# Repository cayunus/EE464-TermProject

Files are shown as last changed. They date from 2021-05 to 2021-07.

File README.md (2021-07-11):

# EE464-TermProject
This repository includes the work put into the design of an isolated DC/DC converter with a 12V output and 100W rating.

Final Presentation: https://docs.google.com/presentation/d/1tAQgM4lNq-ox6lCjjR08sszLsAYqykTbK8jtL-5Cm6U/edit#slide=id.p

Final Report: https://docs.google.com/document/d/1Ga_3vTAyOD3y9dfrS9bvXqfX1RUAF8NENX0YpGBZcNM/edit?usp=sharing

Component List: https://docs.google.com/spreadsheets/d/1R3LbDUZQGh2-h5aSoq4ABOOYQwFWA9nZVz4NNkLxFJc/edit?usp=sharing

Complete Simulation Report: https://docs.google.com/document/d/1Nri5DbtKmKyNQxO-GPV3UCYGi9CR-nUp9evS7hW1Gps/edit?usp=sharing

How to Add .lib files in LTspice: https://www.analog.com/en/technical-articles/ltspice-simple-steps-to-import-third-party-models.html

How to obtain Bode Plot in LTSpice: https://www.analog.com/en/technical-articles/ltspice-basic-steps-in-generating-a-bode-plot-of-smps.html

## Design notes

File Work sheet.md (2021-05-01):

# Work Sheet Rules
* This file is created to use as a work sheet.
* Work sheet can be used for any thing:
  * Important points
  * Question in the mind
  * Problems
  * Lessons learned from experiences
  * Good sources, books and websites.
  * Plans
  * ....

## Important Points
- The chosen topology: > Flyback converter
- Optimization for loss, size and price is highly needed for design process. GUI has been constructed to understand relations between parameters. GUI will be used as tool to define some constraints, requirements and relation for optimization. 
## Plans

- <details>
  <summary>15.04.2021</summary>
  <markdown>
   - Flyback converter controllers have been researching
    - LT8316 has been selected as controller.
    - Controllers have low input voltage limits can be biased with some LDO application with BJT or Mosfet, which results in increase in alternatives of controller.
    - PowiGan controller from Power Integration is kept as option due to advantages of PowiGan in terms efficiency(No opto, Synchronous drive, GaNFET) and compactness. If the controlle for PowiGan can be succeeded, it can be used. 
  </markdown>
</details>

## Questions
- What are parameters that affect selection different shapes of cores?
## Don't reinvent the tire (Lessons)

## Questions&Answers
## Useful Resources and Links
- Information and calculation about saturation of a core visit the [page](http://pigeonsnest.co.uk/stuff/core-saturation.html)
- Core and Shape selection from magnetics [page](https://www.mag-inc.com/Design/Design-Guides/Inductor-Cores-Material-and-Shape-Choices)
## Working sheet
### Halid
### Mehmet
### Yunus

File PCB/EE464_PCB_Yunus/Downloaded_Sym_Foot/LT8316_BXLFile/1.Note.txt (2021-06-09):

NOTE: 

1. BXL files provided represent each model for this generic that share the same package. 

2. Please visit Ultra Librarian Online Reader to convert BXL file into CAD file of your liking.
https://www.ultralibrarian.com/products/online-reader

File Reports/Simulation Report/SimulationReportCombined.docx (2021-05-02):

ELECTRICAL AND ELECTRONICS ENGINEERING DEPARTMENT

EE464 POWER ELECTRONICS – II

COMPLETE SIMULATION REPORT

Halid Filiz 2304632

Mehmet Kılıç 2232262

Yunus Çay 2166148

# 1. Introduction

In this project, we are expected to design an isolated DC-DC converter that is similar to one that is used in Tesla Model S. For this purpose, requirements are analyzed first. The designed circuit should satisfy the requirements below.

- Minimum Input Voltage: 220V
- Maximum Input Voltage: 400V
- Output Voltage: 12V
- Output Power: 100W
- Output Ripple: 4%
- Line Regulation: 3%
- Load Regulation: 3%

After assessing the requirements carefully, the design process is started. First, a suitable topology is selected by discussing the advantages or disadvantages of each topology. After determining the topology, a controller IC options are discussed and the most suitable one is selected. Circuit design process is started with controller IC and other circuit parameters are selected by considering the limitations and requirements of the controller, which are stated şn the datasheet.

After determining the circuit parameters, ideal and non ideal simulations are conducted. According to the simulation results, some changes are made and commercial products are selected for some important power components like switches, capacitors and inductances. Also, magnetic design for the transformer is started.

In this report, work done until now is represented. After taking feedback, design is going to be optimized and improved.

# 2. Topology Selection

To design this isolated DC/DC converter, we had to start by choosing a topology that satisfied our needs. The first was that this converter had to have the input and output isolated from each other. This means that we are limited to isolated topologies. The topologies that we have considered for the design are the flyback, forward and push-pull converter topologies. There are certain advantages and disadvantages for using each of these converters.

One advantage of the flyback converter is that it uses the transformer core as an energy storage element, making an extra inductor unnecessary. This situation makes flyback is a cheaper and simpler option.

Moreover, the group members have experience with flyback converter design from their summer practices and part-time working activities, which makes the flyback converter design process much easier. Therefore, flyback converter is selected to be the primary design option for this project.

While the topologies themselves are important, we must also consider the available IC controllers on the market while making our decision since if we do not have an proper IC for our topology the design is pretty much impossible. There are certain large IC controller manufacturers that have simulation models for their ICs like Analog Devices and Texas Instruments which would make our design process much easier. Therefore, controller ic election holds a crucial role in converter design.

# 3. Controller IC Selection

After researching the conventional controllers, some ics are determined to be possible options are their advantages and disadvantages are discussed. The first option was InnoSwitch3-EP.

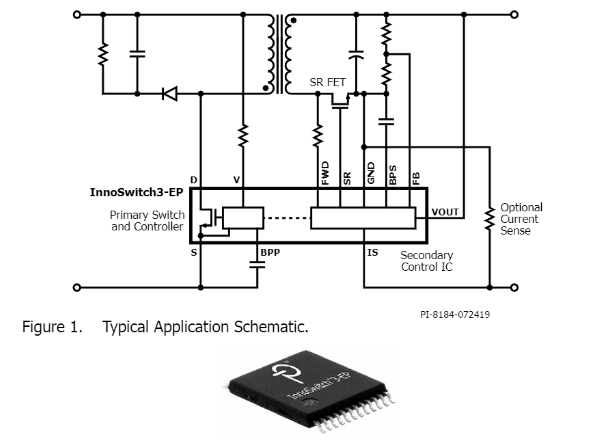
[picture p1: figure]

Figure 1 Alternative controller IC - InnoSwitch3-EP

This controller has an internal GaN MOSFET, which increases the switching efficiency. Also it provides synchronous drive in a single chip. According to the datasheet, no heatsink is required up to 100W. However, there is no simulation model provided for this controller and some details might be missed if it was manually modelled. Therefore, this controller is kept as a back-up plan.

Other two options are LT8316 and LTC3805 manufactured by Analog Devices. Since these devices have built-in models in LTSpice, it is logical to use ICs manufactured by AD. Both of these ICs are used for conventional Flyback Converters with the difference between them being the control and feedback mechanisms. The LTC3805 is a current mode controller with an adjustable frequency between 70kHz and 700kHz. For isolated feedback, this controller must be used in tandem with an opto-coupler driver and an opto-coupler. The advantage of this is that the load and line regulations are essentially perfect, and the frequency of the controller is constant.

The LT8316 on the other hand is a Quasi-resonant boundary operation mode controller and takes its feedback from the third wind of the transformer. The operation frequency of this controller changes depending on the load and while it has very good load and line regulation compared to other no-opto controllers, it does not give the same performance as a controller with an opto-coupler. The main advantage of the LT8316 is that it uses less parts since there is no need for an opto and also that it can be naturally started and then fed from the input and third windings. Both ICs are simulated, and it is seen that both of them satisfy the given conditions and are both suitable designs but in the end we must decide on one of them to continue with our project. Since LT8316 requires less parts, a simpler and cheaper design is possible if it is used. Therefore, LT8316 is selected as the controller of the designed circuit. Datasheets of each IC are provided in the Github repository.

# 4. Transformer Design

Flyback converter isolates a primary side and a secondary side with a transformer. Transformer can be used to step up or down an input voltage according to turns ratio. Besides, input-output relation is the same as buck boost converter. Input-output relation is shown in Equation (1).

| V_o =(N_s)/(N_p)D/(1-D)V_(in) | (1)

Transformer is mainly used for the applications transmitting energy without storage. However, transformer of flyback converter stores an energy, and then passes it to secondary side, which is the reason for why flyback transformer is also called as coupled inductor. Hence, considerations for energy stored, saturation current, inductance are important for transformer design. The design of transformer is started with application information given in the datasheet.

Table 1 shows some system level information and controller requirements having an impact on the transformer design.

Table 1 Parameters for the transformer design

Description | Symbol | Value
Input voltage range | Vin,min - Vin,max | 220V – 400V
Output voltage | Vo | 12V
Max. output power | Pout | 100W
Max. switching frequency | fs | 140kHz
Min. Switch off time* | tOFF(MIN) | 800ns
Min. Switch on time* | tON(MIN) | 300ns
Backup time* | tBU | 50μs

* These parameters will be explained in detail while calculating their limitations on primary inductance.

Application information given in the datasheet determines the minimum and maximum limits for the primary, magnetizing, inductance due to parameters given in Table 1 such as tOFF(MIN), tON(MIN) and tBU. Before finding the limitations, the peak of the primary current should be determined according to working principle of controller and the delivered maximum output power. While the minimum current limit of the controller affects the limitations of primary inductance due to tOFF(MIN) and tON(MIN), the maximum output power has to be satisfied according to magnetic energy storage shown in Equation (2).

| E_(mag) = 1/2Li^2 | (2)

The maximum peak current in primary side can be found from the desired output power. Since the peak current is observed at maximum power and the controller has boundary mode control, the peak current can be calculated as seen in Equation (3). Efficiency is taken as %80 as a safety margin due to practical considerations.

| I_(SW(MAX)) =(2P_(out))/(ɳV_(in) D)=3.75A V_(in) =220V, ɳ=0.8(Eff),P_(out) =100W | (3)

## 4.1. Limitations of Primary Inductance

### I. tOFF(MIN) – Minimum Switch Off Time

The feedback of the output voltage is given through the tertiary winding. The nonzero voltage between the tertiary winding is created when the secondary current flows. The required minimum time to sample voltage by the sample-and-hold error amplifier is 800ns. “In order to ensure proper sampling, the secondary winding needs to conduct current for at least 800ns.” [1] The limitation due to tOFF(MIN) is given in Equation (4).

| L_m ≥(t_(OFF(MIN)) N_p (V_o +V_F ))/(I_(SW(MIN)))=0.11mH N_p =8 Turns, V_F =0.7V(Diode), I_(SW(MIN)) =0.2*I_(SW(MAX)) =0.75A | (4)

### II. tON(MIN) – Minimum Switch Off Time

The controller has a minimum switch on time for the sake of blanking initial switch turn-on current spike. The current, ISW(MIN), should not be reached for tON(MIN), which creates restriction on the selection of flyback transformer in terms of magnetizing inductance. The limitation due to switch on time is determined in Equation (5).

| L_m ≥(t_(ON(MIN)) V_(in(MAX)))/(I_(SW(MIN)))=0.16mH | (5)

### III. Power Storage Capability of the Transformer

Equation (2) shows the magnetic energy stored in an inductor for a given current and inductance. Since the flyback transformer stores magnetic energy due to working principle of flyback converter, the inductance of transformer should be able to store sufficient power. Equation (6) shows the limitation of the inductance due to magnetic energy storage.

| L_m ≥(2(V_o +V_F )I_(o(MAX)))/(ɳI_(SW(MAX))^2 f_(s(MAX)))=0.14mH | (6)

### IV. Backup Time

Backup timer is stimulated to avoid low output voltage levels. Backup timer turns the primary switch on unless the secondary side diode turns off. This feature restricts the inductance value with maximum limit. Limitation of inductance of flyback transformer due to backup time can be seen in Equation (7).

| L_m <(0.8 N_p (V_o +V_F )t_(BU))/(I_(SW(MAX)))=1.08mH | (7)

## 4.2. Determination of Turns Ratio

The output voltage is lower than the input voltage level. Transformer should step down the input voltage for reasonable values so that sensitivity of duty cycle should not be high, i.e., duty cycle below %10 is problem for controllers. Therefore, the turns ratio should be high as much as possible to keep duty cycle in a range between %50 and %20.

Turns ratio has also impact on breakdown voltage of semiconductors. Table 2 shows maximum terminal voltages of the primary switch and the secondary diode. The turns ratio has reverse effect on the semiconductors. While turns ratio, N, increases reverse voltage of the primary switch, it reduces reverse voltage of the secondary diode.

Table 2 Relation between turns ratio and reverse voltage of the semiconductors

Semiconductor | General Formulation for Reverse Voltage
Primary switch | VDS = Vin + N(Vo + VF) + VLeakage
Secondary diode | VR = (Vin/N) + (Vo + VF)

The turns ratio is selected as 8, which keep the duty cycle between %20 and %30. Also, this selection can be optimized value in terms of reverse voltage of semiconductors and duty cycle. The increase in reverse voltages results in increase in switching losses and decrease in safety margin of devices. Duty cycle of the flyback converter in a range of input voltage is shown in Figure 2.

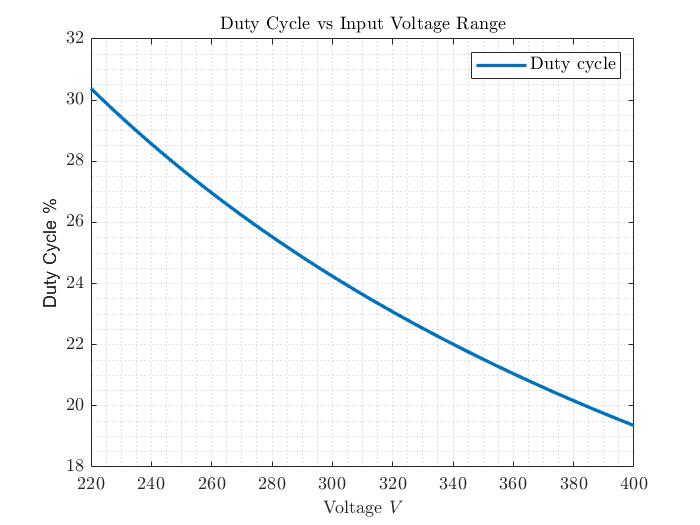
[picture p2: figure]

Figure 2 Duty cycle vs input voltage range for 8 turns ratio, N

## 4.3. Determination of the Primary Inductance

In the part 0 , 0.16mH and 1.08mH are founded as minimum and maximum limitations, respectively. The value between the limits may probably work. However, safety margin for each limit should be determined to eliminate unexpected practical issues. The safety region for each limit can be taken as %25 of limiting value above and below for minimum and maximum limits, respectively. Hence, the primary inductance value should be between 0.2mH and 0.81mH.

The boundary mode control requires variable switching frequency according to the load. When the primary switch is on, the inductor current starts from the zero. Therefore, the frequency relation between frequency and inductance for the same input voltage and output voltage is obvious, which is shown in Equation (8). Since duty cycle and turns ratio is constant, switching frequency and primary inductance are inversely proportional for the same amount of inductor current ripple. The inductor current ripple is determined according to output power.

| ΔI_(L,ON) =(DT_s V_(in))/(L_m) ΔI_(L,OFF) =((1-D)T_s (V_(in) +N(V_o +V_F )))/(L_m) | (8)

Transition to DCM occurs as the load decreases. Duty cycle calculation in DCM can be seen in Equation (9). Both calculations are the same except the Pout, Vo, and R relation.

| D=(V_o)/(V_(in))(√(2L_m f_s))/(√R) D=(√(2P_(out) L_m f_s))/(V_(in)) | (9)

Supply of the input power occurs during the on time of primary switch. Therefore, the current ripple of the inductor is directly related with the delivered power. Equation (10) shows the inductor current ripple calculation in DCM, which shows that Lm and fs are also inversely proportional in DCM.

| ΔI_L =(V_o √2)/(√(RL_m f_s)) | (10)

According to analysis of the relation between Lm and fs, increase in Lm results in low switching frequency, hence, low switching loss. On the other hand, boundary mode and DCM eliminate turn-on loss of the primary switch and reverse recovery of the secondary diode. Even if the increase in Lm can be beneficial for switching losses, the tradeoff due to increase in Lm is increase in size of flyback transformer and increase in windings, which causes more copper and core losses. The question that there is a relation between copper, core losses and frequency. Actually, this type of relations are the signs of need in optimization.

After considering iterative relation between Lm and fs, the Lm, primary inductance, is chosen as 0.4mH.

## 4.4. Core Selection

Core selection is based on shape of a core, size of a core and magnetic characteristics of a core. First, selection based on magnetic characteristics of a core is analyzed.

### I. Magnetic Characteristics of Core

General approach for the selection of core type is divided into two for flyback transformer; distributed air-gap powder cores and gapped ferrite cores. Both type of cores has advantages. For example, ferrite cores provide a core with more permeability. On the other, distributed air-gap powder cores may have less core loss compared to gapped ferrite cores.

Distributed air-gap powder core is selected based on magnetic characteristics, which can stimulate an efficiency, winding area and mechanical robustness.

Powder cores are classified. These classifications are mainly based on core loss, maximum flux density, permeability, and cost, which can be seen in Figure 3 taken from the Magnetics. Kool Mu is selected due to optimal permeability and core loss values. Besides, Kool Mu is preferred due to relative low prices.

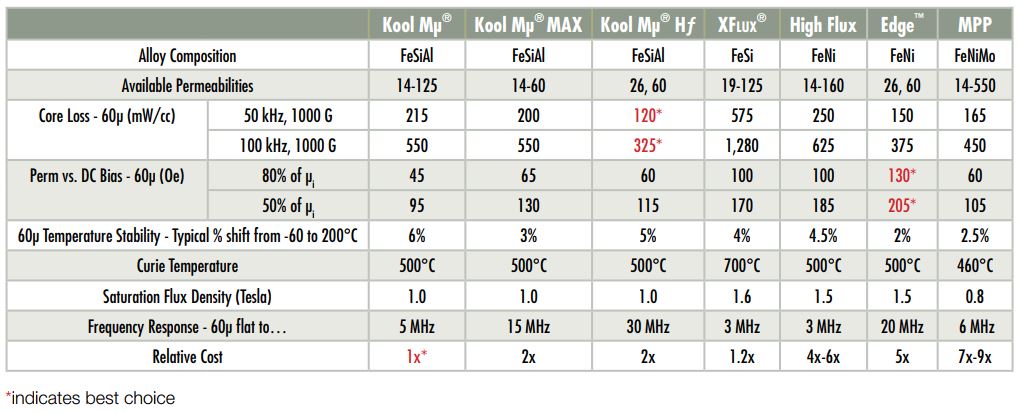
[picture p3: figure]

Figure 3 Classification of powder cores [2]

### II. Shape of Core

Common preference for flyback transformers is toroidal shape. The copper loss can be decreased with both toroidal shape and E shape according to the current situation. While toroidal shapes have permeability between 14μ-125μ, E shapes have maximum 90μ relative permeability. However, E shapes have relatively higher Ae, area. Also, the window area may be higher in toroids. Hence, toroidal shape is selected.

### III. Size of Core

Size of core will be determined from available manufactured cores. Cores are researched on Magnetics (https://www.mag-inc.com/). Selected cores are tested whether they satisfy limitations due to inductance, flux density, saturation current, fill factor. The constructed GUI on MATLAB is used to test scores. Constructed GUI can be seen in Figure 4.

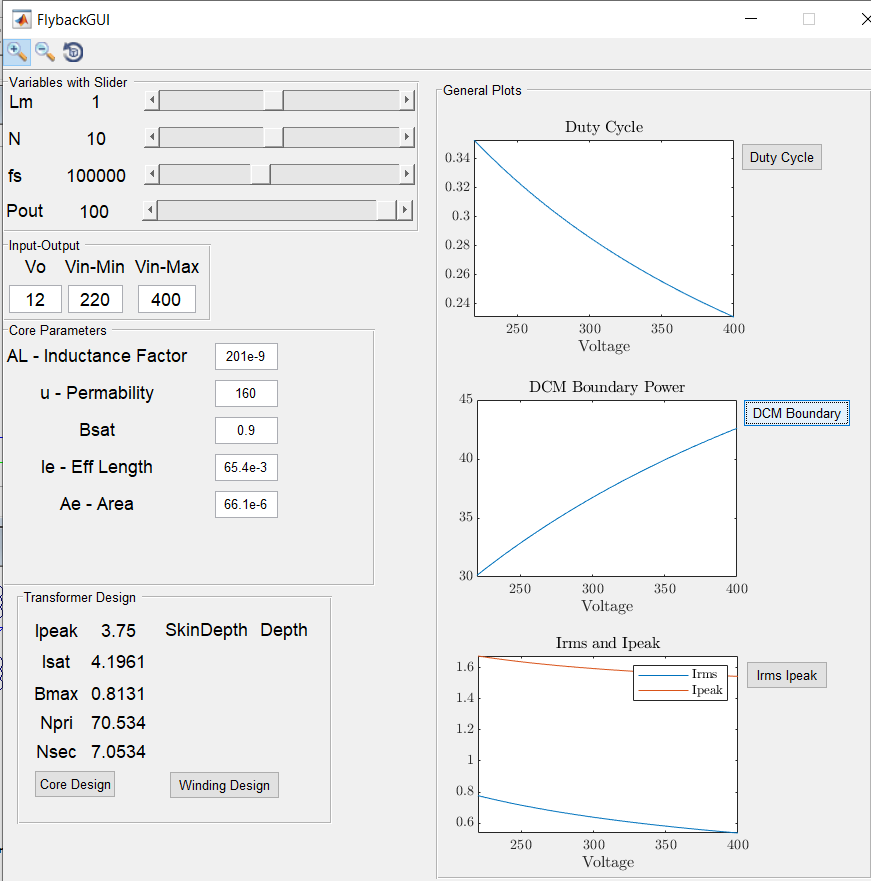
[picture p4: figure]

Figure 4 The constructed GUI on MATLAB for flyback converter design

Peak current value of the primary side is calculated ISW(MAX) that equals to 3.75A with safety margin. Safety margin is determined according to %80 efficiency of converter. The safety margin for saturation current of a core can be taken as %10, since the efficiency creates a sufficient safe region. Hence, minimum saturation current is 4.1A.

Kool Mu cores have 10,500 Gauss saturation level, which is approximately equal to 1 Tesla. Since the saturation current and created maximum flux density are proportional to each other, saturation can be checked from both created maximum flux density and peak current of the primary side.

Copper losses are also important due to AC resistance and number of windings. The optimization for copper losses based on core selection can be stimulated with selection of cores with high inductance factor, AL.

Equation (11) shows the calculation of saturation current and the created maximum flux.

| I_(sat) =(B_(sat) A_e)/(√(L_m A_L)) B_(max) =(N_p I_(peak) μ)/(l_e) | (11)

Table 3 shows the comparison of different cores. Table 3 shows the cores are in order from high volume to low volume. Core 3 is the most suitable one for required saturation limits. Hence, the core 3 is selected. Inductance factor would be more to decrease windings but there is no available Kool Mu core.

Table 3 Comparison Kool Mu cores in different sizes and inductance factors

Parameters | Core 1 930 | Core 2 350 | Core 3 310
Bsat (Tesla) | 0.9 | 0.9 | 0.9
μ - Permeability | 125 | 125 | 125
AL – Inductance factor(nH/T^2) | 157 | 105 | 90
Le – eff length (mm) | 63.5 | 58.8 | 56.7
Ae – Area (mm2) | 65.4 | 38.8 | 31.7
Isat (A) | 7.42 | 5.4 | 4.76
Bmax (Tesla) | 0.47 | 0.62 | 0.69
Np (Turns) | 50.5 | 61.7 | 66.7
Ns and Nthird (Turns) | 6.3 | 7.7 | 8.3

## 4.5. Winding and Fill Factor

Maximum switching frequency of the controller LT8316 is 140kHz. However, 140kHz switching is not observed at high load. LT8316 works in boundary mode for high load and as load increases, switching period should be increased according to Equation (8). Thus, AC resistance is not as much as higher at high load. Skin depth is relatively low at high voltage. Figure 5 given in datasheet also explains the case.

Figure 5 Switching frequency vs load, LT8316

Cable diameter should not be selected according to maximum switching frequency. The selection of cable according to maximum switching frequency may cause selection of cable having small area so that conduction losses at high load becomes high.

Even if the most reliable option to calculate AC resistances due to skin effect and proximity effect is finite element analysis, there are also other methods such as Dowell’s equation. These calculations will be done after simulation. Now, the skin depth is only calculated, and it can be seen in Equation (12). Output current equals 8.3A at full load, which results in approximately 60 kHz for 320V input. Hence, we can calculate the skin effect at 60kHz switching frequency. Besides, temperature of copper is assumed 80°C.

| δ=1/(√(πf_s σ_(Cu) μ_(Cu)))=0.296mm | (12)

When radius of a cable is selected as equal to skin depth, the whole area of the core can be used so that there will be no excessive cable thickness. As the frequency increases, AC resistance will increase. However, since the load will become less, copper loss can be negligible. AWG23 cable can be used for the primary side.

The current passing through the secondary side cable is eight times of the primary side current and the frequency is the same. At full load, secondary side should be capable to sink 8.3Adc, 11Arms. Since the ampacity of AWG23 for 75°C rating at 30°C ambient is approximately 5A, two parallel winding of AWG23 cable can be used. On the other hand, the tertiary winding can be wound with AWG30. Since the tertiary winding is solely used to get feedback, there is a very small current. Table 4 shows the windings details and fill factor.

Table 4 Transformer cable sizes and fill factor

| AWG | # of Turns | Copper Area
Primary | 23 | 67 | 17.3 mm²
Secondary | 23 | 8.3 x2 | 4.3 mm²
Tertiary | 30 | 8.3 | 0.83 mm²
Total | NA | 92 | 22.43 mm²
Fill Factor | (22.43mm^2)/(139mm^2)=0.16

# 5. Simulations

After finalizing the analytical calculations, the simulation model is constructed and simulated. For simulations we are using LTSpice since we have opted to use controllers manufactured by Analog Devices. LTSpice is a SPICE-based analog electronic circuit simulation software that is produced by the semiconductor manufacturer Analog Devices. It is the most widely used distribution of the SPICE software. Here the LTC3805 and LT8316 designs have been analyzed and the resulting waveforms have been taken. The efficiency report has been added for the LTC3805 design but could not be done for the LT8316. Though from the simulations we observed similar efficiency values for both.

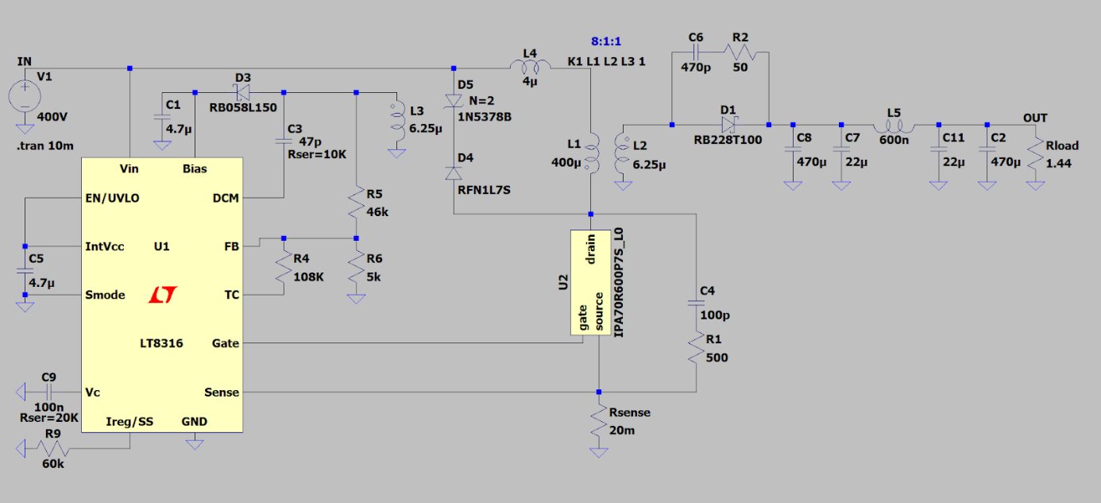
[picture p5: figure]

Figure 6 LTSpice schematic for the No Opto Flyback Converter (LT8316)

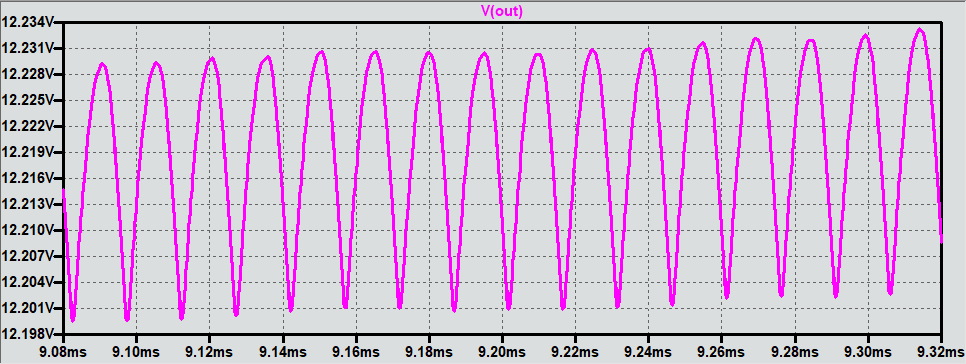
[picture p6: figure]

Figure 7 Output voltage of converter at full load and 400V input (LT8316)

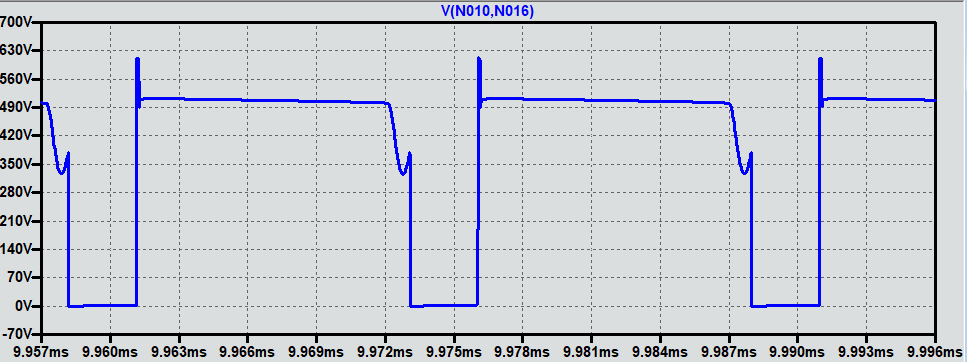
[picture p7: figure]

Figure 8 Voltage on the MOSFET at full load and 400V input (LT8316)

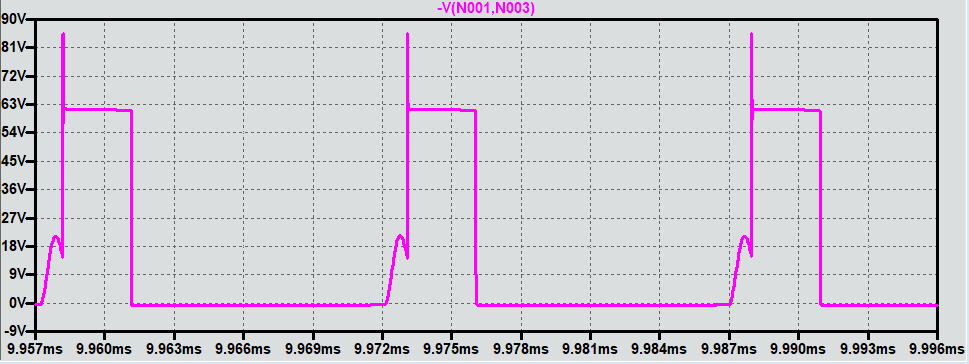
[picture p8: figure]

Figure 9 oltage on the Diode at full load and 400V input (LT8316)

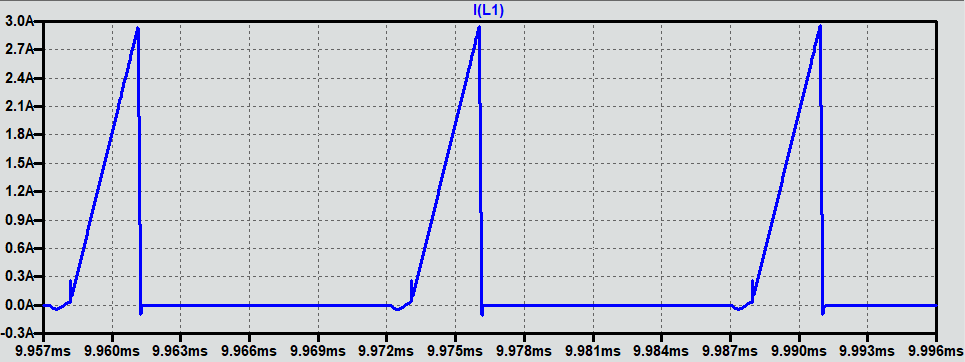
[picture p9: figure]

Figure 10 Current waveforms of the transformer’s primary at full load and 400V input (LT8316)

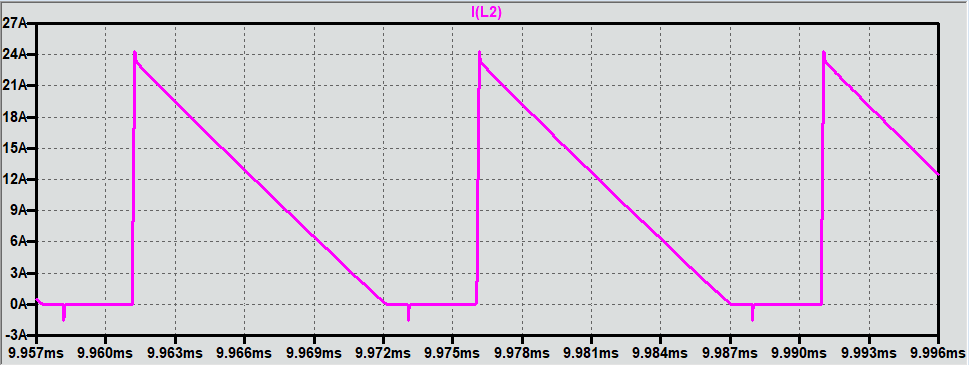
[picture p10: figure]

Figure 11 Current waveforms of the transformer’s secondary at full load and 400V input (LT8316)

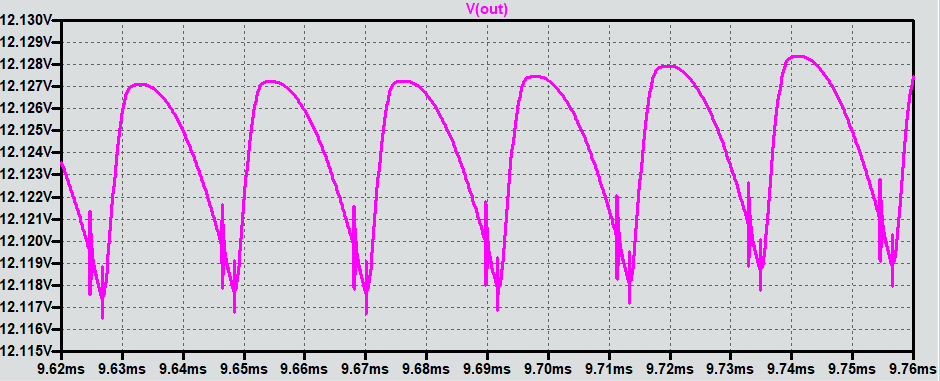
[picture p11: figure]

Figure 12 Output voltage of converter at 10% load and 220V input (LT8316)

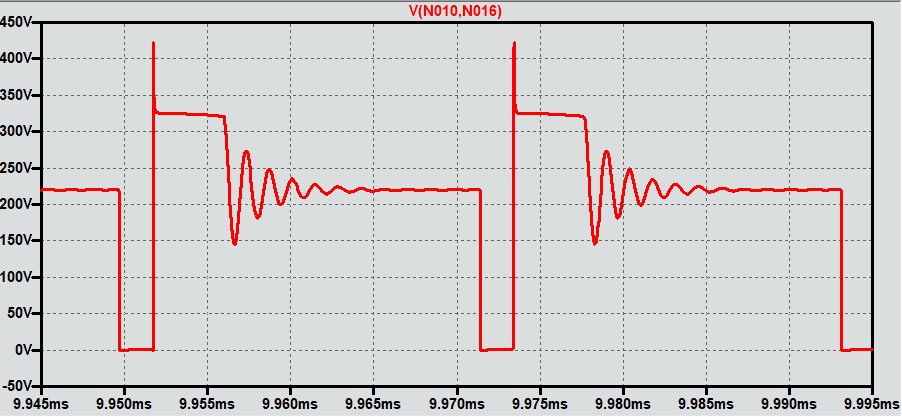
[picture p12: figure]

Figure 13 Voltage on the MOSFET at 10% load and 220V input (LT8316)

Figure 14 Voltage on the Diode at 10% load and 220V input (LT8316)

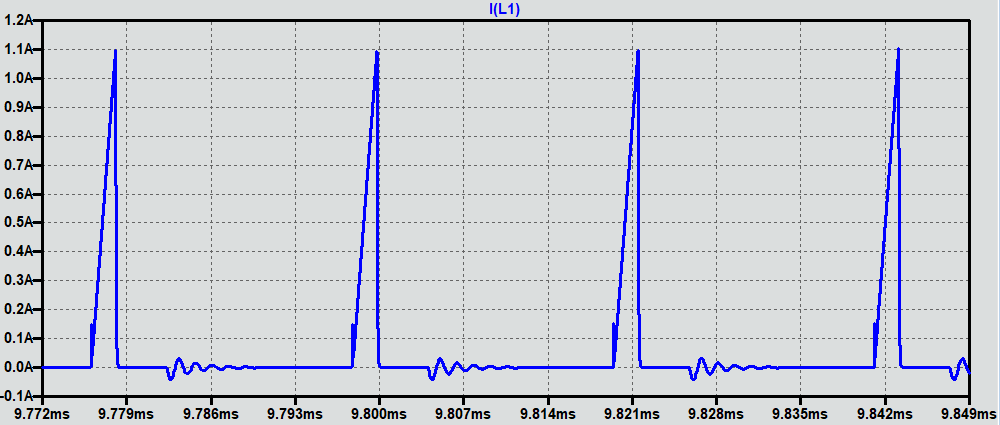
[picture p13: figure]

Figure 15 Current waveforms of the transformer’s primary at 10% load and 220V input (LT8316)

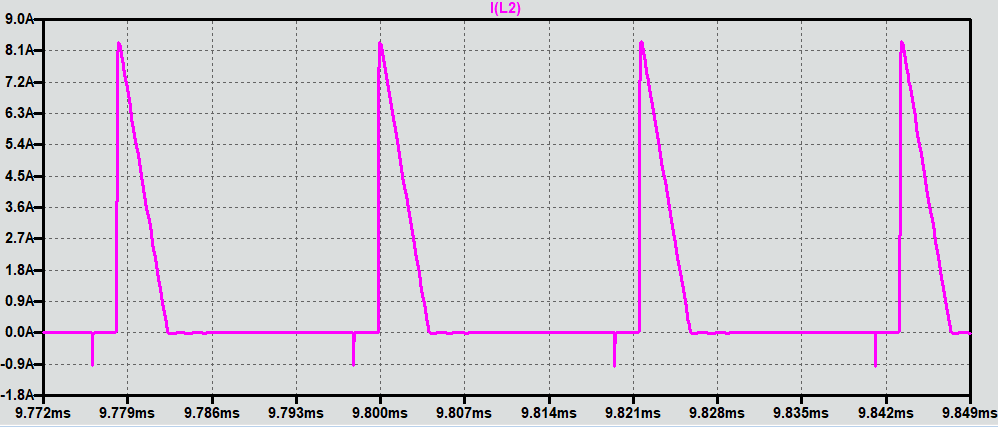
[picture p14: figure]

Figure 16 Current waveforms of the transformer’s secondary at 10% load and 220V input (LT8316)

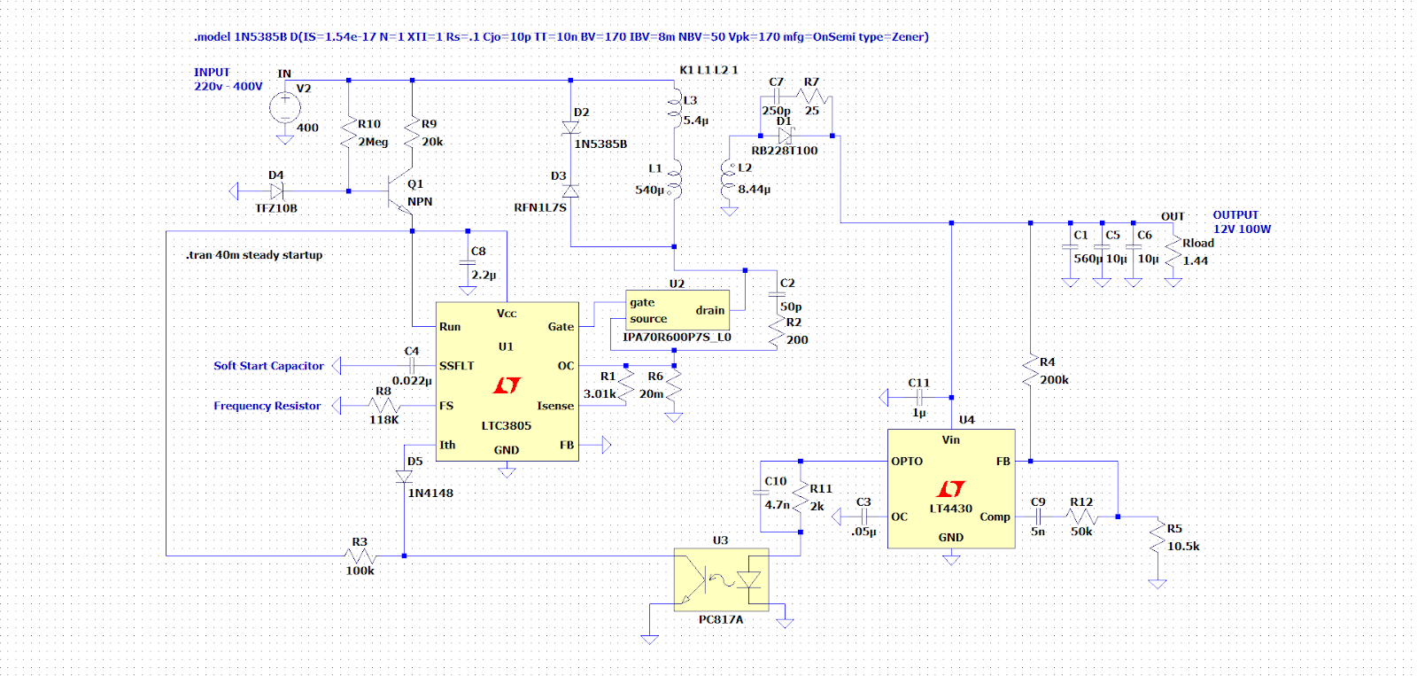
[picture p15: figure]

Figure 17 LTSpice schematic for the Flyback Converter with Opto (LTC3805)

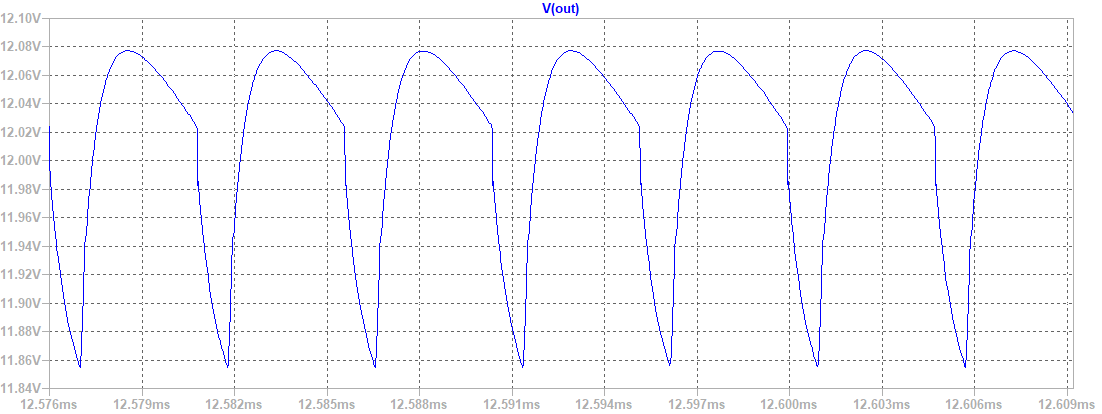
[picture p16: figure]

Figure 18 Output voltage of converter at full load and 400V input (LTC3805)

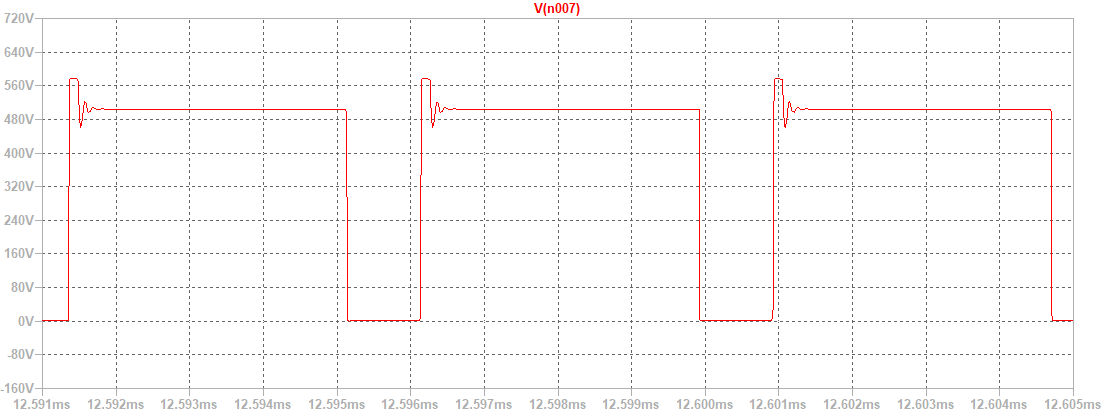
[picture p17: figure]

Figure 19 Voltage on the MOSFET at full load and 400V input (LTC3805)

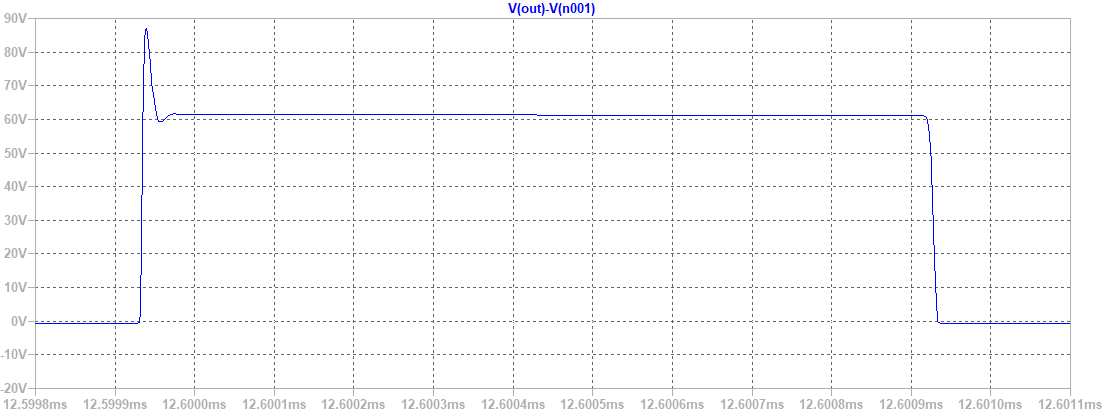
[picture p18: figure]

Figure 20 Voltage on the Diode at full load and 400V input (LTC3805)

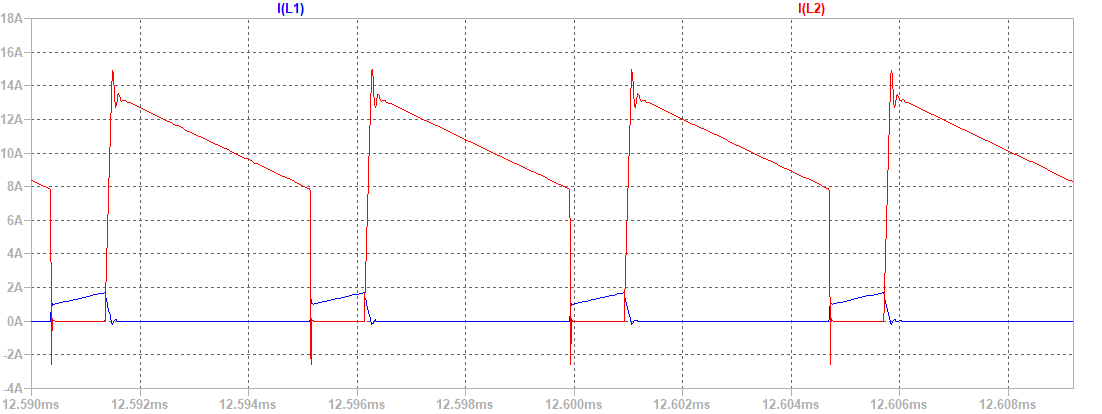
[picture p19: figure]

Figure 21 Current waveforms of the transformer’s primary and secondary at full load and 400V input (LTC3805)

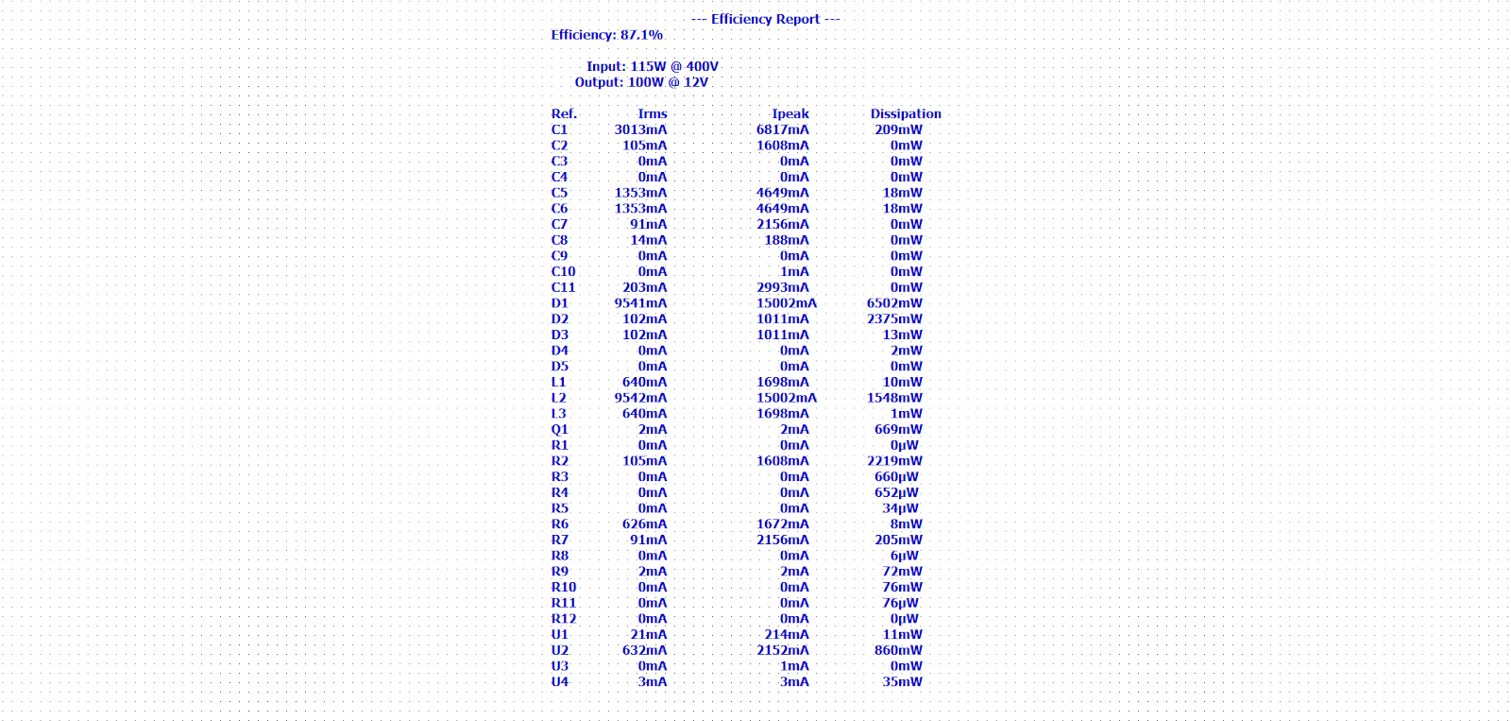
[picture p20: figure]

Figure 22 Efficiency report from LTSpice for the full load 400V input case (LTC3805)

Figure 23 Output voltage of converter at 10% load and 220V input (LTC3805)

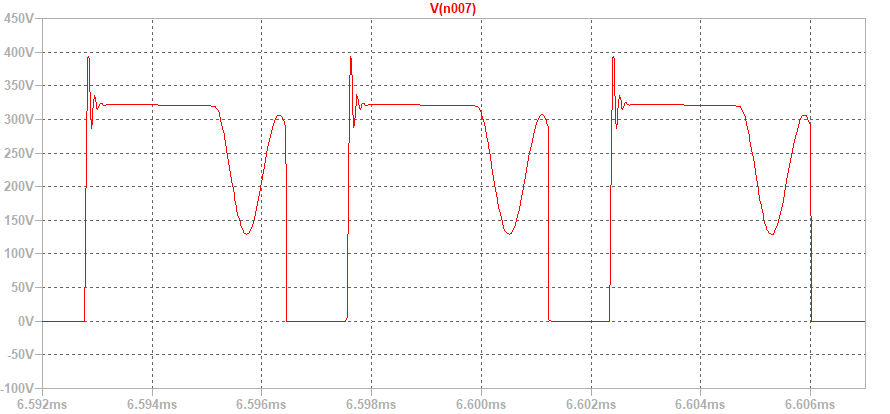
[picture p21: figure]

Figure 24 Voltage on the MOSFET at 10% load and 220V input (LTC3805)

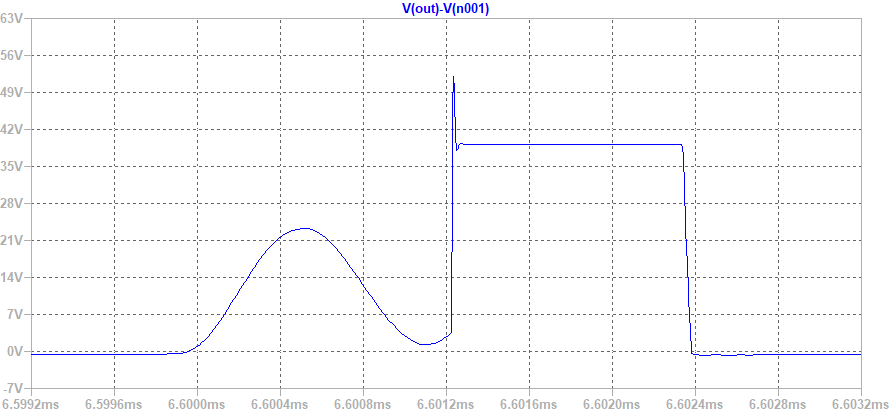
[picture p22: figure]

Figure 25 Voltage on the Diode at 10% load and 220V input (LTC3805)

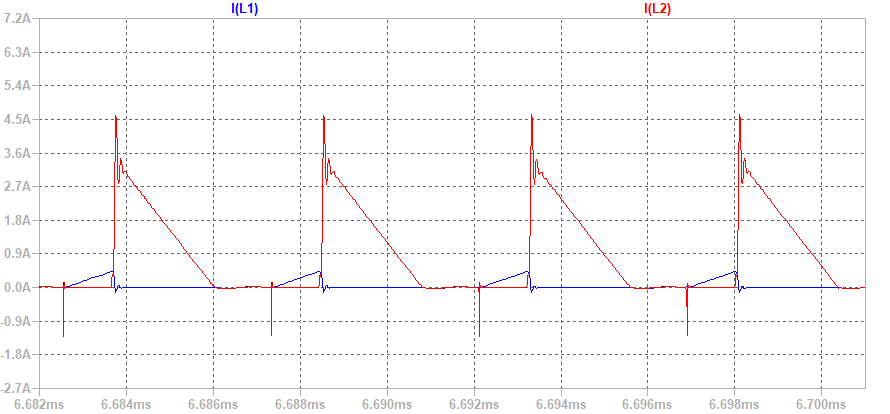
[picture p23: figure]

Figure 26 Current waveforms of the transformer’s primary and secondary at 10% load and 220V input (LTC3805)

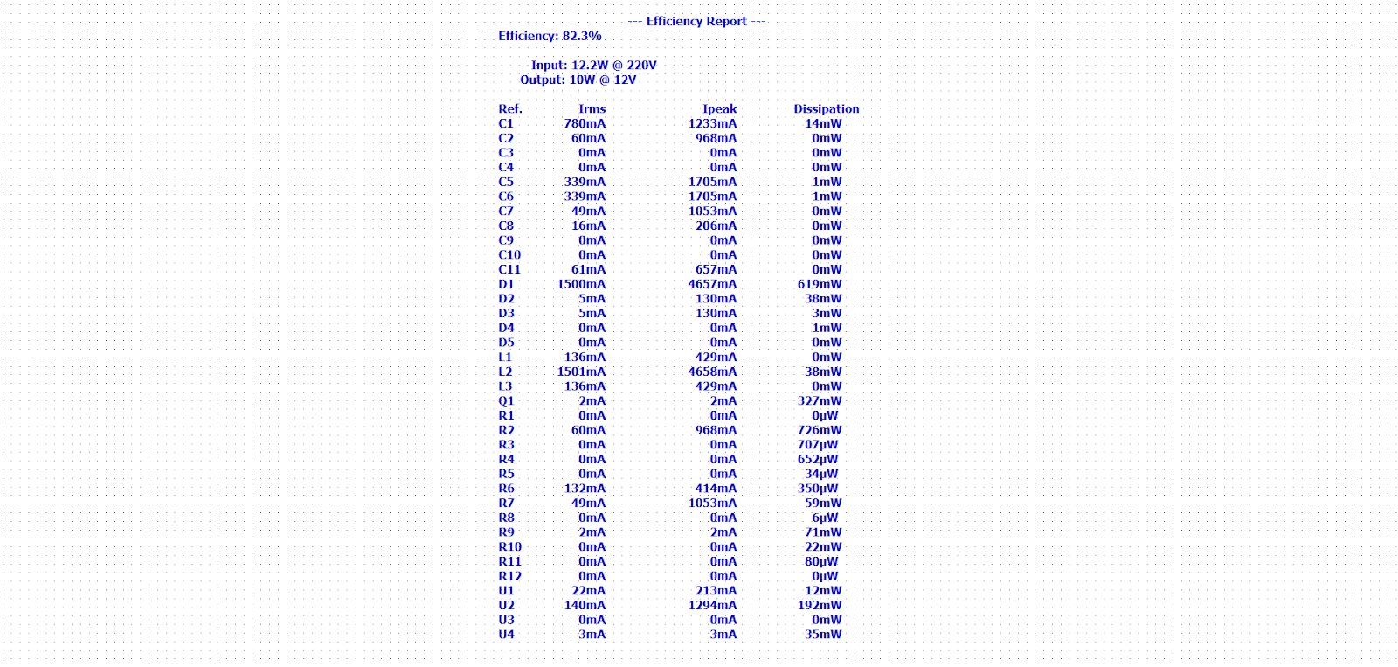
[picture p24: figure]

Figure 27 Efficiency report from LTSpice for the 10% load 220V input case (LTC3805)

Simulation results for both LTC3805 and LT8316 are given above. As seen in the results, both designs satisfy the project requirements for both full load and light load cases. However, LT8316 provides a simpler design.

# 6. Component Selection

After simulating the circuit with LT8316, power components are selected. Although all the control and auxiliary components need to be selected at the end of the project, only the power components are considered yet. Because most of the cost and parasitic effects come from the power elements.

First, power MOSFET is selected according to the simulation results. At full load, peak voltage between drain and source terminals are approximately 630 V and peak current through the drain terminal is 3A. These values are considered while determining the ratings of the MOSFET. Controller IC can provide switching frequency up to 140kHz, which can create a high switching loss and thermal dissipation. By considering all the limitations above and adding some safety margin, IPA70R600P7S CoolMOS Power MOSFET is selected. Table below shows the ratings of this MOSFET. Detailed datasheet can be found in the Github repository.

Table 5 MOSFET parameters

VDS | 700 V
RDS(ON) | 0.6 Ω
ID,max | 20 A
Qg | 10.5 nC

Second, the secondary diode is selected. According to the simulation results, peak voltage on the diode is approximately 85V and peak current is approximately 25A. Since this diode can create a large switching loss, a schottky diode is preferred instead of a minority carrier diode. By considering these limitations, SS10PH9 Schottky diode which is manufactured by Vishay Semiconductor is selected. Table below shows the diode ratings.

Table 6 Diode Parameters

VR | 100 V
IF,average | 10 A
IF,peak | 200 A
VF | 0.661 V

After the switches, output capacitors are selected. There are two different types of capacitors at the output: 22uF and 470uF. Since the 22uF capacitors will most probably have a small ESR and be cheap, they will be selected later. For now, only the 470uF capacitors are selected. Output voltage is 12V. Capacitance and voltage ratings are considered with some safety margin while selecting the capacitors. Therefore, A750EQ477M1CAAE015 capacitors that are produced by KEMET are selected. Table below shows the ratings of these capacitors.

Table 7 Output Capacitor Ratings

VDC | 16 V
C | 470 uF
ESR @100kHz | 15 mΩ

Note that the LT8316 controls the circuit with variable frequency. As the switching frequency changes, impedances of capacitors may vary and for some high frequencies, they can even lose their capacitive characteristics and behave like a resistance or an inductor. To guarantee that the capacitors keep their characteristics, frequency analysis must be done. Most probably there will not be any problem. However, such an analysis is going to be conducted in the final report for reliability.

At the output of the converter, a CLC filter is used instead of a simple capacitor. For this filter, an inductor with 600nH inductance is required. According to the simulation results, peak current through this inductor is 24A and average current is 8.33A. These ratings are considered while selecting the inductor. ASPIAIG-F7030-R60 is chosen at the end. Table below shows the ratings of the inductor.

Table 8 Inductor Ratings

L | 600 nH
R | 3.2 mΩ
Saturation Current | 32 A
Temperature Rise Current | 23 A

To decrease the cost, the inductor may be designed instead of just buying it. This option will be considered after the feedback.

Finally, clamper circuit diodes are selected. Note that there is a schottky diode at the bias pin of the controller and snubbers for the MOSFET and secondary diodes. Since these parts face less stress than the ones are discussed here, they are selected in the future. In the clamper circuit, two zener (in series) and one normal diode are used. During the simulations, voltage and current stress on them are observed and selections are made according to the measurements. RFN1L7SSD is selected for the minority carrier diode and 1N5378B is selected for the zener diodes. Tables below show their ratings.

Table 9 Diode Ratings

Repetitive Peak Rev. Voltage | 700 V
Average Current | 0.8 A
Non-Rep. Surge Current | 15 A
Reverse Recovery Time | 45 ns

Table 10 Zener Diode Ratings

Zener Voltage | 105 V
Max. Steady State Power Dissipation | 5 W
Non-Rep. Surge Current | 1.5 A

After selecting some important components, a cost table is constructed to project the total cost and make changes in the elements if needed.

Table 11 Cost of Selected Components

Component | Unit Cost ($)
IPA70R600P7S CoolMOS Power MOSFET | 0.47
SS10PH9 Schottky diode | 0.39
A750EQ477M1CAAE015 Capacitor | 0.16
ASPIAIG-F7030-R60 Inductor | 0.86
RFN1L7SSD Diode | 0.2
1N5378B Zener Diode | 0.14
LT8316 Controller | 3.35
Total | 5.57

# 7. Conclusion

Flyback topology is selected to implement isolated DC/DC converter from variable input voltage range (220V-400V) to 12V output with 100W output power. Advantages due to low size with single inductor and popularity are the parameters to select Flyback topology.

LT8316 is selected among some other alternative controllers such as PowiGan - InnoSwitch3-EP by Power Integrations, which is restricted by requirement of controller simulation. Since Analog Devices has LTSpice models of controllers, LT8316 is easily implemented on the simulation tool.

Determination of the topology and the controller have took us to design the transformer and clamp circuit, select semiconductor and output filter. Clamp circuits and semiconductor ratings depends on each other and they have been selected with that consideration. On the other hand, even if the transformer design have rule of thumbs and requirements, there is a huge gap for optimization in terms of core loss, copper loss and size. Thus, selection of turns ratio, primary inductance and winding have been explained in detail.

Finally, simulation report will be enhanced with further improvents on efficiency, thermal simulations and PCB design. Also, constructed GUI shown in Figure xxx will be used to optimize the converter in terms of efficiency, size and cost.

# 8. References

[1] Analog Devices LT8316 Datasheet

https://www.analog.com/media/en/technical-documentation/data-sheets/lt8316.pdf

[2] Magnetics – Kool Mu cores properties

https://www.mag-inc.com/Products/Powder-Cores

Sensitivity: Public

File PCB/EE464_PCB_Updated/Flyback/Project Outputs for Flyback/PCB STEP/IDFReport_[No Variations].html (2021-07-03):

Altium customize

# IDF File Translation Report

Date: | | 3.07.2021
Time: | | 16:04:23
Elapsed Time: | | 00:00:00
PCB Filename | : | D:\Users\26055743\OneDrive - ARÇELÝK A.Þ\Desktop\EE464_PCB\EE464-TermProject\PCB\EE464_PCB_Updated\Flyback\Flyback_PCB.PcbDoc
IDF Board Filename | : | D:\Users\26055743\OneDrive - ARÇELÝK A.Þ\Desktop\EE464_PCB\EE464-TermProject\PCB\EE464_PCB_Updated\Flyback\Project Outputs for Flyback\PCB STEP\[No Variations].emn
IDF Library Filename | : | D:\Users\26055743\OneDrive - ARÇELÝK A.Þ\Desktop\EE464_PCB\EE464-TermProject\PCB\EE464_PCB_Updated\Flyback\Project Outputs for Flyback\PCB STEP\[No Variations].emp

Errors

Back to top

Warnings

Back to top

Save Warnings

Back to top

Save Errors

Back to top

Export Warnings

Back to top

Export Errors

Back to top

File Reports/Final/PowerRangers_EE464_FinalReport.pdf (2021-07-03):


# ELECTRICAL AND ELECTRONICS ENGINEERING DEPARTMENT

# EE464 POWER ELECTRONICS – II FINAL REPORT

Halid Filiz | 2304632
Mehmet Kılıç | 2232262
Yunus Çay | 2166148

## Table of Contents

Introduction | 3
Topology Selection | 3
Controller IC Selection | 5
Transformer Design | 6
4.1. Limitations of Primary Inductance | 8
tOFF(MIN) – Minimum Switch Off Time | 8
tON(MIN) – Minimum Switch Off Time | 8
Power Storage Capability of the Transformer | 9
Backup Time | 9
4.2. Determination of Turns Ratio | 9
4.3. Determination of the Primary Inductance | 11
4.4. Core Selection | 12
Magnetic Characteristics of Core | 12
Shape of Core | 13
Size of Core | 14
4.5. Winding and Fill Factor | 15
Simulations | 16
Component Selection | 22
Thermal Calculations | 25
PCB Design | 26
Thermal Simulations | 30
Protection | 35
Conclusion | 35
References | 36

# 1. Introduction

In this project, we were expected to design an isolated DC-DC converter that meets the set requirements. For this purpose, we first look at the requirements. The designed circuit should satisfy the requirements below.

- Minimum Input Voltage: 220V
- Maximum Input Voltage: 400V
- Output Voltage: 12V
- Output Power: 100W
- Output Ripple: 4%
- Line Regulation: 3%
- Load Regulation: 3%

We assess the requirements carefully and then start the design process. First, a suitable topology is selected by discussing the advantages or disadvantages of each topology. After determining the topology, the controller IC options are discussed and the most suitable one is selected. Circuit design process is started with controller IC and other circuit parameters are selected by considering the limitations and requirements of the controller, which are stated in the datasheet.

After determining the circuit parameters, we conduct some simulations. According to the simulation results, some changes are made and commercial products are selected for some important power components like switches, capacitors and inductances. Also, magnetic design for the transformer is done after assessing the requirements of the circuit.

After that, we do some thermal calculations to see whether the components need any additional cooling. We then design the PCB to meet the set requirements. Finally we use software to thermally analyze the completed product.

# 2. Topology Selection

To design this isolated DC/DC converter, we start by choosing a topology that satisfies the needs of our project. The first and most critical requirement is that this converter had to have the input and output isolated from each other. This means that we are limited to isolated topologies. The topologies that we have considered for the design are the flyback, forward and push-pull converter topologies. There are certain advantages and disadvantages for using each of these converters.

The advantage of the flyback converter is that it uses the transformer core as an energy storage element, making an extra inductor unnecessary. This situation makes flyback a cheaper and simpler option. The disadvantage of the flyback is that the transformer needs to be larger compared to other topologies in order to avoid high core losses. The flyback is not suited for high power conversion and the required 100W is certainly not low but falls just in range of the recommended power of a flyback. We must also keep in mind that the output current will exceed an average of 8A and have a RMS value even higher. Due to this the component in charge of rectification at the output will dissipate a lot of heat if it happens to be a diode. Due to this synchronous switching is preferred.

Also it is worth noting that the group members have experience with flyback converter design from their summer practices and part-time working activities, which makes the flyback converter design process much easier. Therefore, a flyback converter is selected to be the primary design option for this project.

While the topologies themselves are important, we must also consider the available IC controllers on the market while making our decision since if we do not have a proper IC for our topology the design is pretty much impossible. There are certain large IC controller manufacturers that have simulation models for their ICs like Analog Devices and Texas Instruments which would make our design process much easier. Therefore, controller IC selection holds a crucial role in converter design.

# 3. Controller IC Selection

After researching the conventional controllers, some ICs are determined to be possible solutions and their advantages and disadvantages are further discussed. The first option available was the InnoSwitch3-EP.


Figure 1 Alternative controller IC - InnoSwitch3-EP

This controller has an internal GaN FET, which increases the switching efficiency while also decreasing required parts. Also, it provides a synchronous drive for the secondary in a single chip. According to the datasheet, no heatsink is required up to 100W. However, there is no simulation model provided for this controller and some critical details might be missed if it was manually modelled. Therefore, this controller is discarded as an option.

Other two options are LT8316 and LTC3805 manufactured by Analog Devices. Since these devices have built-in models in LTSpice, it is logical to use ICs manufactured by AD. Both of these ICs are used for conventional Flyback Converters with the difference between them being the control and feedback mechanisms. The LTC3805 is a current mode controller with an adjustable frequency between 70kHz and 700kHz. For isolated feedback, this controller must be used in tandem with an opto-coupler driver and an opto-coupler. The advantage of this is that the load and line regulations are essentially perfect, and the frequency of the controller is constant. The main disadvantage is that it requires too many components for too few benefits.

The LT8316 on the other hand is a Quasi-resonant boundary operation mode controller and takes its feedback from the third winding of the transformer. The operation frequency of this controller changes depending on the load and while it has very good load and line regulation compared to other no-opto controllers, it does not give the same performance as a controller with an opto-coupler. The main advantage of the LT8316 is that it uses less parts since there is no need for an opto and also that it can be naturally started and then fed from the input and third windings. Both ICs are simulated, and it is seen that both of them satisfy the given conditions and are both suitable designs but in the end, we must decide on one of them to continue with our project. Note that by using a Secondary-Side Synchronous Rectifier Driver or more specifically the LT8309, we can get rid of the output diode and replace it with a MOSFET with low Rds to dramatically increase efficiency. Also, this IC works without any feedback from the primary side. Keeping this in mind we decide to use the LT8316 in conjunction with the LT8309 to achieve an efficient and simple system.

# 4. Transformer Design

Flyback converter isolates a primary side and a secondary side with a transformer. Transformer can be used to step up or down an input voltage according to the turns ratio. Besides, the input-output relation is the same as a buck boost converter. Input-output relation is shown in Equation (1).

V

o =

Ns
N
p

D
1−D V
in

(1)

Transformer is mainly used for the applications transmitting energy without storage. However, the transformer of the flyback converter stores energy, and then passes it to the secondary side, which is the reason for why the flyback transformer is also called a coupled inductor. Hence, considerations for energy stored, saturation current, inductance are important for transformer design. The design of the transformer is started with application information given in the datasheet.

Table 1 shows some system level information and controller requirements having an impact on the transformer design.

Table 1 Parameters for the transformer design

Description | Symbol | Value
Input voltage range | Vin,min - Vin,max | 220V – 400V
Output voltage | Vo | 12V
Max. output power | Pout | 100W
Max. switching frequency | fs | 140 kHz
Min. Switch off time* | tOFF(MIN) | 800ns
Min. Switch on time* | tON(MIN) | 300ns
Backup time* | tBU | 50μs

* These parameters will be explained in detail while calculating their limitations on primary inductance.

Application information given in the datasheet determines the minimum and maximum limits for the primary, magnetizing, inductance due to parameters given in Table 1 such as tOFF(MIN), tON(MIN) and tBU. Before finding the limitations, the peak of the primary current should be determined according to the working principle of the controller and the delivered maximum output power. While the minimum current limit of the controller affects the limitations of primary inductance due to tOFF(MIN) and tON(MIN), the maximum output power has to be satisfied according to magnetic energy storage shown in Equation (2).

E

mag =

1
2

Li

2
(2)

The maximum peak current in the primary side can be found from the desired output power. Since the peak current is observed at maximum power and the controller has boundary mode control, the peak current can be calculated as seen in Equation (3). Efficiency is taken as %90 as a safety margin.

I

peak =

2P
out
ηV
in

D = 3. 37A

V

in = 220V, η = 0. 9, D = 0. 3, P

out = 100W

(3)

## 4.1. Limitations of Primary Inductance

### I. tOFF(MIN) – Minimum Switch Off Time

The feedback of the output voltage is given through the tertiary winding. The nonzero voltage between the tertiary winding is created when the secondary current flows. The required minimum time to sample voltage by the sample-and-hold error amplifier is 800ns. “In order to ensure proper sampling, the secondary winding needs to conduct current for at least 800ns.” [1] The limitation due to tOFF(MIN)

is given in Equation (4).

L | = 0.12mH
m

>

t
OFF(MIN)

N(V

o+R
ds

I
o(RMS)

)
I
SW(MIN)

N = 8, R

ds = 5mΩ, I | SW(MIN) = 0. 70A, I o(RMS) = 13A

(4)

### II. tON(MIN) – Minimum Switch Off Time

The controller has a minimum switch on time for the sake of blanking initial switch turn-on current spike. The current, ISW(MIN), should not be reached for tON(MIN), which creates restrictions on the selection of the flyback transformer in terms of magnetizing inductance. The limitation due to switch on time is determined in Equation (5).

L | = 0.17mH
m

>

t
ON(MIN)

Vin(MAX)
I
SW(MIN)

(5)

### III. Power Storage Capability of the Transformer

Equation (2) shows the magnetic energy stored in an inductor for a given current and inductance. Since the flyback transformer stores magnetic energy due to the working principle of the flyback converter, the inductance of the transformer should be able to store sufficient power. Equation (6) shows the limitation of the inductance due to magnetic energy storage.

L | = 0.15mH
m

>

2(V

o+R
ds

I
o(RMS)

)I
o(RMS)
ηI
SW(MAX)

f
s(MAX)

(6)

### IV. Backup Time

Backup timer is stimulated to avoid low output voltage levels. Backup timer turns the primary switch on unless the secondary side diode/switch turns off. This feature restricts the inductance value with maximum limit. Limitation of inductance of the flyback transformer due to backup time can be seen in Equation (7).

L | = 1.1mH
m

<

0.8N(V

o+R
ds

I
o(RMS)

)t
BU
I
SW(MAX)

(7)

## 4.2. Determination of Turns Ratio

The output voltage is lower than the input voltage level. Transformer should step down the input voltage for reasonable values so that sensitivity of duty cycle should not be high, i.e., duty cycle below %10 is a problem for controllers. Therefore, the turns ratio should be as high as possible to keep the duty cycle in a range between %50 and %20.

Turns ratio also has an impact on breakdown voltage of semiconductors. Table 2 shows maximum terminal voltages of the primary switch and the secondary switch. The turns ratio has a reverse effect on the semiconductors. While the turns ratio, N, increases reverse voltage of the primary switch, it reduces reverse voltage of the secondary switch.

Table 2 Relation between turns ratio and reverse voltage of the semiconductors

Semiconductor | General Formulation for Reverse Voltage
Primary switch | VDS = Vin + N(Vo + Rds Io(RMS) 2 ) + VLeakage
Secondary switch | VR = (Vin /N) + (Vo + Rds Io(RMS) 2 ) + VLeakage

The turns ratio is selected as 8, which keeps the duty cycle between %20 and %30. Also, this selection can be optimized in terms of reverse voltage of semiconductors and duty cycle. The increase in reverse voltages results in increase in switching losses and decrease in safety margin of devices. Duty cycle of the flyback converter in a range of input voltage is shown in Figure 2.


Figure 2 Duty cycle vs input voltage range for N=2

## 4.3. Determination of the Primary Inductance

In the part 4.1, 0.17mH and 1.1mH are found as minimum and maximum limitations, respectively. The value between the limits may probably work. However, the safety margin for each limit should be determined to eliminate unexpected practical issues. The safety region for each limit can be taken as %25 of limiting value above and below for minimum and maximum limits, respectively. Hence, the primary inductance value should be between 0.2mH and 0.81mH.

The boundary mode control requires variable switching frequency according to the load. When the primary switch is on, the inductor current starts from the zero. Therefore, the frequency relation between frequency and inductance for the same input voltage and output voltage is obvious, which is shown in Equation (8). Since duty cycle and turns ratio is constant, switching frequency and primary inductance are inversely proportional for the same amount of inductor current ripple. The inductor current ripple is determined according to output power.

∆I

L,ON =

DT
s

V
in
Lm

∆I

L,OFF =

(1−D)T
s

(V

in+N(V

o+R
ds

I
o(RMS)

))
Lm

(8)

Transition to DCM occurs as the load decreases. Duty cycle calculation in DCM can be seen in Equation (9). Both calculations are the same except the Pout, Vo

, and R relation.

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
Supply of the input power occurs during the on time of primary switch. Therefore, the current ripple of the inductor is directly related to the delivered power. Equation (10) shows the inductor current ripple calculation in DCM, which shows that Lm and fs are also inversely proportional in DCM.

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
(10)

According to analysis of the relation between Lm and fs

, increase in Lm results in low switching frequency, hence, low switching loss. On the other hand, boundary mode and DCM eliminate turn-on loss of the primary switch and reverse recovery of the secondary diode. Even if the increase in Lm can be beneficial for switching losses, the tradeoff due to increase in Lm is increase in size of flyback transformer and increase in windings, which causes more copper and core losses. The problem is that there is a relation between copper, core losses and frequency. Actually, this type of relations are the signs of need in optimization.

After considering the iterative relation between Lm and fs

, the primary inductance is chosen to be between 0.4-0.5mH.

## 4.4. Core Selection

Core selection is based on the shape of a core, size of a core and magnetic characteristics of a core. Here we will determine the type, shape, size and air gap of the core.

### I. Magnetic Characteristics of Core

General approach for the selection of core type is divided into two for flyback transformers; distributed air-gap powder cores and gapped ferrite cores. Both types of cores have their own advantages. For example, ferrite cores provide more permeability and higher frequency of operation with less core losses. On the other hand, distributed air-gap powder cores may have less air gap loss compared to gapped ferrite cores and they also have higher saturation points.

Ferrite core with an air-gap is selected based on the fact that they are more commonly used in flyback transformers and also provide much more options compared to their distributed gap counterparts.

### II. Shape of Core

Common preference for flyback transformers is some kind of core similar to E type core where the core is made up of two pieces. The reason for this is while toroidal cores are more efficient due to their geometry, they are very difficult to use while mass manufacturing transformers since the winding process is hard to automate. On the other hand other core shapes allow us to use bobbins to wind the windings before we put them in the core. In the end we chose the ETD type cores since they seem to be recommended for higher power applications.


Figure 3 The core chosen for the flyback transformer

### III. Size of Core

Size of core will be determined from available manufactured cores. Cores are researched on the TDK website and are readily available at Mouser.

From our calculations in MATLAB, we decide to use B66361G1000X187 which is an ETD34 core and has a gap of 1 mm on each piece which gives us an AL of 153 nH/N

2

Equation (11) shows the turns needed to achieve around 500μH.

N

p =

Lm
A
L

= 57. 16 Turns ≈ 56 Turns

### N = 7 Turns

s =

N
p
8

L

m = A
L

N
p

2 = 479. 81µH

(11)

We use the equation below to calculate the maximum flux density Bm using the effective cross sectional area Ae

(cm²
) for the core selected. Bm is recommended to be in the range of 0.2 tesla to 0.3 tesla due to the fact that below 0.2 the core would be underused, and above 0.3 there may be a possibility of saturation occurring depending on the ferrite material used.

Equation (12) shows the calculation of maximum flux density.

B

m =

Lm

I
peak
N
p

A
e

= 0. 297T

(12)

We conclude that this core satisfies our requirements.

The AC flux density (BAC) can be used with the core loss curves from manufacturers. This gives the AC component of the magnetic flux instead of the peak to peak. This is simple in the case of a discontinuous transformer design and is simply calculated from Equation (13).

B

AC =

Bm
2 = 149 mT

(13)


Figure 4 Power loss for the material used in the core at 50kHz

From Figure 4 we see that we have a core loss of about 110mW per cm³ when the converter is operating at full load. The core has a volume of 7.63 cm³ per set and this amounts to about 839mW of power loss for the whole core. Also when we use the resistance and IRMS values of the primary and secondary, we find the copper loss to be about 500mW. This means that the total loss seen on the transformer at full load is 1339mW.

## 4.5. Winding and Fill Factor

A common rule of thumb for cable selection in a transformer is to assume the current density to be 4 A/mm²
. Using an AWG chart, we find the recommended wire types which allows us to have our desired current density. We decided to use AWG22 for the primary and AWG12 for the secondary windings. AWG28 is more than enough for the tertiary winding. The window area with the bobbin is 122 mm²

Table 3 Transformer cable sizes and fill factor

AWG | # of Turns | Cross Section of Chosen Cable

Total Cross
Section Area

Primary | 22 | 56 | 0.327 mm² | 18.31 mm²
Secondary | 12 | 7 | 3.31 mm² | 23.17 mm²
Tertiary | 28 | 7 | 0.08 mm² | 0.56 mm²
Total | - | 70 | - | 42.04 mm²
Fill Factor | 34.46%

We find the fill factor to be satisfactory since with the inclusion of insulation tape and such the available window area will be filled. Also since we must take in account the skin effect of the windings, the chosen windings will either have to use litz wire equivalent to the selected AWG rating or choose multiple thinner wires to have the same area as the selected wires and combine them. In the end we opted to use multiple strands of AWG28 wire due to the fact that its skin effect can be ignored for the entirety of the converter's frequency range.

# 5. Simulations

After finalizing the analytical calculations, the simulation model is constructed and simulated. For the simulations we are using LTSpice since we have opted to use controllers manufactured by Analog Devices. LTSpice is a SPICE-based analog electronic circuit simulation software that is produced by the semiconductor manufacturer Analog Devices. It is the most widely used distribution of the SPICE software. Here the converter design with the LTC8316 and LT8309 controllers are implemented and have been analyzed. The resulting waveforms have been captured and displayed below.


Figure 5 LTSpice Schematic of the Circuit

Figure 6 Output Voltage at Full Load 220V Input


Figure 7 Primary MOSFET Voltage at Full Load 220V Input

Figure 8 Secondary MOSFET Voltage at Full Load 220V Input


Figure 9 Transformer Current at Full Load 220V

Figure 10 Output Voltage at 10% Load 220V Input


Figure 11 Output Voltage at Full Load 400V Input

Figure 12 Primary MOSFET Voltage at Full Load 400V Input


Figure 13 Secondary MOSFET Voltage at Full Load 400V Input

Figure 14 Transformer Current at Full Load 400V


Figure 15 Output Voltage at 10% Load 400V Input

The converter is simulated in LTSpice and the resulting waveforms are given above. All the voltage and load regulation requirements are satisfied. From the MOSFET waveforms we will choose our switches accordingly.

# 6. Component Selection

There are three main component groups in this circuit. Power components, peripheral components of the ICs and protective components.
Peripheral components of the controller and secondary MOSFET driver are selected by following the guidelines given in datasheets. Power components are selected by considering the simulation results and some safety margin. These components are discussed in the simulation report. However, there are some new components that were added for synchronous switching update. In this report, only primary and secondary MOSFETs are dis
Primary MOSFET is selected according to the simulation results. At full load, peak voltage between drain and source terminals are approximately 630 V and peak current through the drain terminal is 3A. These values are considered while determining the ratings of the MOSFET. Controller IC can provide switching frequency up to 140kHz, which can create a high switching loss and thermal dissipation. By considering all the limitations above and adding some safety margin, IPA70R600P7S CoolMOS Power MOSFET is selected. Table below shows the ratings of this MOSFET. Detailed datasheet can be found in the Github repository.

Table 4: Primary MOSFET parameters

V @T=25 𝇈C DS | 700 V
R DS(ON) | 0.6 Ω
I D,max | 20 A
Qg | 10.5 nC

Secondary MOSFET is selected by adopting the same approach. Although voltage stress on it is relatively smaller than the primary MOSFET, secondary MOSFET should be able to handle approximately 10 A. Therefore, BSC040N10NS5 OptiMOS 5 Power MOSFET of the Infineon is selected. Some of its ratings are given below.

Table 5: Secondary MOSFET parameters

V @T=25 𝇈C DS | 100 V
R DS(ON) | 4 mΩ
I D,max | 18 A
Qg | 58 nC

In final simulations including models of selected components, results were satisfying. Finally, total cost of 1000 boards are calculated, including PCB, case transformer cost. Final Bill of Materials report is given below. Total cost of the board for 1000 pieces is 18,8 $. Selection of protective devices is discussed in the protection section.

Table 6: BOM


# 7. Thermal Calculations

From LTSpice we take the worst case for all the components that dissipate more than 250mW of power.
- Primary MOSFET: | 615 mW
- Secondary MOSFET: | 620 mW
- Zener Clamp (per Zener): | 505 mW
- Primary RC Snubber: | 1325 mW
- Flyback Transformer: | 1339 mW

If we assume ambient temperature to be 25

| o
, then we can calculate the highest possible temperatures seen on the components using their thermal resistances from the data sheet.

Primary MOSFET:
T

max = T
Ambient
+ R | tℎJA P loss = 25 + 80 × 0. 615 = 74. 2 °C

Secondary MOSFET:
The thermal resistance is increased to 75 W/K from 50 W/K, since the defined copper area in the datasheet is not equal to the copper area of the secondary MOSFET.
T

max = T
Ambient

+ R
tℎJA

P

loss = 25 + 75 × 0. 620 = 71. 5 °C

Zener Clamp:
T

max = T
Ambient

+ R
tℎJA

P

loss = 25 + 135 × 0. 505 = 93. 17 °C

Note that this is for the worst case and disregards the copper in the PCB.

Primary Snubber Resistor:
Although we could not find the thermal resistance of the resistor, in the datasheet we see that there is a chart that shows the temperature of the component with respect to the dissipated power. At full load, this resistor reaches about 70 C

o
. This is assuming

Flyback transformer:
From the equation below we can find the temperature of the transformer.

T

max = T
Ambient

+

P

loss ( Surface Area )

0.833
= 25 +

1339

( 30 )

0.833
= 47. 67 C

◦

From our calculations and observations we see that there is no need for a separate heatsink.

# 8. PCB Design

PCB is drawn according to prioritized loops and components. Loops, traces and components having impact on EMI are drawn at first. Figure xx1 shows the definition of the loops for flyback SMPS.


Figure 16: Current Loops in the Flyback Converter

As shown in Figure 16, the input loop and the power switch loop belong to the primary side of PCB. These loops are intentionally drawn short and wide for the sake of minimization of parasitic inductance and resistance. The width of traces for power current is defined as 2mm, which is higher than for the case temperature rise of traces equals 10°C. The importance of traces for power switch loop is significant since power switch loop current is pulsating DC. Hence, the di/dt of the power switch loop could be sensitive to parasitic inductances.

The 3D view, top and bottom layers of the designed PCB are given below. Detailed schematic and other drawings can be found in the appendix section.


Figure 17: 3D View

Figure 18: Top View


Figure 19: Bottom View

Figure 20: Top Layer


Figure 21: Bottom Layer

Primary side has importance due to the snubber circuits and gate loop having significantly high di/dt and dv/dt signal characteristics. Thus, these loops are also drawn short and wide, which can be seen in Figure 21.

Primary side polygons for power and ground are also placed without violation of clearance since the maximum input voltage is 400V. Polygons decrease trace inductance and resistance, minimize ground loops and decrease EMI effects. While diminish in inductance, resistance and length of ground loops is obvious, EMI effect can be explained with shielding. When the bottom and top layer is covered by copper, high frequency magnetic flux is absorbed on copper area as an eddy current loss.

Secondary side is designed with the same considerations. Traces having high di/dt and current rates are kept wide and short. Actually, a polygon plane is used to the region that carries 10 A current to decrease the resistance of the copper area. Controller signal traces are tried to be placed such that analog signals are affected from high current traces less. Top-bottom placement is determined by considering compactness and thermal management. Trace and plane clearances are considered during the placement. Clearance between primary and secondary sides is 1,5 cm at least.

# 9. Thermal Simulations

Thermal simulation is applied on PCB with SolidWorks Thermal Simulation tool. According to thermal calculations, there is no need to heatsink and natural convection of air is sufficient to keep components on PCB in operating conditions.

Thermal simulation on PCB requires some information about material characteristics of components, power loss, thermal resistance of contacts and convection coefficient of air. After determination of requirements, components and PCB are meshed. The size of mesh is defined according to material size. For instance, the triangular mesh size for the transformer is 2mm and the mesh for snubber resistance is 0.6mm. On the other hand, even if the smaller mesh size results in more accurate results, the simulation time increases inversely with size of the mesh. Figure 22 shows the meshed PCB and components.


Figure 22

Thermal characteristics of semiconductors and the board, FR4, are determined according to the Engineering Database in Flow Simulation toolbox in SolidWorks. Thermal contact resistances between components and board is determined with consideration of soldering and junction-to-lead thermal resistances. For instance, solder has 50 W/m.K thermal conductivity. When the soldering area and length of soldering are considered, approximation for thermal contact resistance becomes 1.5 K/W based on the application not by ONSemi, AN9596. [2] Hence, as we can see that thermal contact resistances are relatively small.

Simplification of PCB in terms of thermal analysis is important and sometimes, it is a requirement. The simplification on PCB is done with filtering out many components which have no significant power loss. Moreover, the simplification of the 3D model of components is also very handy with CircuitWorks in order to mesh PCB properly. Simplification has a drawback that surface and contact area are changed slightly. However, according to the webinar by NineDot Connects, most of the simplifications in CircuitWorks have no significant effect on thermal analysis. [3] Figure 22, simplified model of PCB and components by CircuitWorks


Figure 23

Power loss of components are calculated at 220V input case, since it is the case in which efficiency of the circuit is the worst. The power loss of each component shown in the Thermal Calculations part is assigned and the convection coefficient is taken as 20. The maximum temperature is observed on snubber resistance. The value can be taken as pretty much, but there is still approximately a 30 °C margin for the maximum point of optimum operating range. Thermal analysis of the PCB can be seen in top and bottom views in Figure 24 and 25.


Figure 24: Thermal Simulation top view

Figure 25: Thermal Simulation bottom view


Figure 26: Thermal Simulation 3D view

The temperatures of components are measured in Figure 27 and Figure 28. The closeness of snubber resistance, R9, clamp zeners, D3 and D4, and primary mosfet, Q1, results in a high temperature in R9. However, the most important parameter making snubber hot is the small volume of the resistor package. Convection of air on snubber resistance is relatively low due to the small volume. Therefore, some thermal vias are added and the board is strengthened in the snubber resistance side.


Figure 27: Thermal Simulation bottom view, component temperatures

Figure 28: Thermal Simulation top view, component temperatures

# 10. Protection

Protection components, fuse and TVS, are added against high current and high voltage, respectively. Fuse interrupts the input when the maximum current rating of the fuse is exceeded. In order to provide a sustainable current protection, a fuse holder is placed on the PCB. Fuse is placed in this holder and can be changed in case of melting. Fuseholder is placed just after the neutral connector of the input. 3D view of the fuse holder is given below.


Figure 29: Input Connector and Fuseholder

TVS is used for suppress the input voltage transients. Controller IC receives its supply voltage directly from the input voltage. Therefore, it is important to limit the input voltage in case of fast transients like spikes. Maximum continuous supply voltage for the IC is 600V. Therefore, an TVS is selected such that input voltage is clamped to the 600-650V region during transients from 10 to 100 µs.
Finally, it can be concluded that our circuit is protected from input overcurrent and voltages with fuse and TVS usage.

# 11. Conclusion

Flyback topology is selected to implement the isolated DC/DC converter from variable input voltage range (220V-400V) to 12V output with 100W output power. The abundance of readily available ICs and the simplicity of the flyback converter were the main reasons for our decision.

LT8316 is selected among some other alternative controllers and is used in conjunction with the LT8309 for a more efficient design. The use of the LT8309 has provided the design a 6% increase in efficiency due to the absence of the forward voltage drop we would otherwise see in a diode. Since Analog Devices has LTSpice models of controllers, LT8316 and LT8309 are easily implemented on the simulation tool.

Determination of the topology and the controller have given us some parameters to follow while designing the transformer and clamp circuit and also selecting the semiconductors. Clamp circuits and semiconductor ratings depend on each other and they have been selected with that consideration. On the other hand, even if the transformer design has rule of thumbs and requirements, there is a huge gap for optimization in terms of core loss, copper loss and size. Thus, selection of turns ratio, primary inductance and winding have been explained in detail.

We have done the thermal calculations and decided that there is no need for any heatsinks. The PCB has also been designed and any protection circuit we have come up with has been added to the design. In the end we used Solidworks to run a thermal simulation on the finished product.

The end results are a product that meets the demands given to us and has a peak simulated efficiency of around 95%. We acknowledge the fact that this number will probably be less in real life.

# 12. References

[1] Analog Devices LT8316 Datasheet

https://www.analog.com/media/en/technical-documentation/data-sheets/lt8316.pdf

[2] On Semiconductor, A Quick PCB Thermal Calculation for Power Electronic Devices with Exposed Pad Packages

https://www.onsemi.com/pub/Collateral/AND9596-D.PDF

[3] Beyond a Heatsink - Thermal Considerations in PCB Design. Webinar

https://youtu.be/wEdn9kPAX1I


Power traces are shown with thick wires. They will be short and wide

There are two ground planes. They are connected with a capacitor

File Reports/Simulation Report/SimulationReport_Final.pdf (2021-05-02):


## ELECTRICAL AND ELECTRONICS ENGINEERING

## DEPARTMENT

## EE464 POWER ELECTRONICS – II

## COMPLETE SIMULATION REPORT

Halid Filiz | 2304632
Mehmet Kılıç | 2232262
Yunus Çay | 2166148

## Contents

# Introduction

In this project, we are expected to design an isolated DC-DC converter that is similar to one

that is used in Tesla Model S. For this purpose, requirements are analyzed first. The designed

circuit should satisfy the requirements below.

- Minimum Input Voltage: 220V
- Maximum Input Voltage: 400V
- Output Voltage: 12V
- Output Power: 100W
- Output Ripple: 4%
- Line Regulation: 3%
- Load Regulation: 3%

After assessing the requirements carefully, the design process is started. First, a suitable

topology is selected by discussing the advantages or disadvantages of each topology. After

determining the topology, a controller IC options are discussed and the most suitable one is

selected. Circuit design process is started with controller IC and other circuit parameters are

selected by considering the limitations and requirements of the controller, which are stated şn

the datasheet.

After determining the circuit parameters, ideal and non ideal simulations are conducted.

According to the simulation results, some changes are made and commercial products are

selected for some important power components like switches, capacitors and inductances. Also,

magnetic design for the transformer is started.

In this report, work done until now is represented. After taking feedback, design is going to be

optimized and improved.

# Topology Selection

To design this isolated DC/DC converter, we had to start by choosing a topology that satisfied

our needs. The first was that this converter had to have the input and output isolated from each

other. This means that we are limited to isolated topologies. The topologies that we have

considered for the design are the flyback, forward and push-pull converter topologies. There

are certain advantages and disadvantages for using each of these converters.

One advantage of the flyback converter is that it uses the transformer core as an energy storage

element, making an extra inductor unnecessary. This situation makes flyback is a cheaper and

simpler option.

Moreover, the group members have experience with flyback converter design from their

summer practices and part-time working activities, which makes the flyback converter design

process much easier. Therefore, flyback converter is selected to be the primary design option

for this project.

While the topologies themselves are important, we must also consider the available IC

controllers on the market while making our decision since if we do not have an proper IC for

our topology the design is pretty much impossible. There are certain large IC controller

manufacturers that have simulation models for their ICs like Analog Devices and Texas

Instruments which would make our design process much easier. Therefore, controller ic election

holds a crucial role in converter design.

# Controller IC Selection

After researching the conventional controllers, some ics are determined to be possible options

are their advantages and disadvantages are discussed. The first option was InnoSwitch3-EP.


Figure 1 Alternative controller IC - InnoSwitch3-EP

This controller has an internal GaN MOSFET, which increases the switching efficiency. Also

it provides synchronous drive in a single chip. According to the datasheet, no heatsink is

required up to 100W. However, there is no simulation model provided for this controller and

some details might be missed if it was manually modelled. Therefore, this controller is kept as

a back-up plan.

Other two options are LT8316 and LTC3805 manufactured by Analog Devices. Since these

devices have built-in models in LTSpice, it is logical to use ICs manufactured by AD. Both of

these ICs are used for conventional Flyback Converters with the difference between them being

the control and feedback mechanisms. The LTC3805 is a current mode controller with an

adjustable frequency between 70kHz and 700kHz. For isolated feedback, this controller must

be used in tandem with an opto-coupler driver and an opto-coupler. The advantage of this is

that the load and line regulations are essentially perfect, and the frequency of the controller is

constant.

The LT8316 on the other hand is a Quasi-resonant boundary operation mode controller and

takes its feedback from the third wind of the transformer. The operation frequency of this

controller changes depending on the load and while it has very good load and line regulation

compared to other no-opto controllers, it does not give the same performance as a controller

with an opto-coupler. The main advantage of the LT8316 is that it uses less parts since there is

no need for an opto and also that it can be naturally started and then fed from the input and third

windings. Both ICs are simulated, and it is seen that both of them satisfy the given conditions

and are both suitable designs but in the end we must decide on one of them to continue with

our project. Since LT8316 requires less parts, a simpler and cheaper design is possible if it is

used. Therefore, LT8316 is selected as the controller of the designed circuit. Datasheets of each

IC are provided in the Github repository.

# Transformer Design

Flyback converter isolates a primary side and a secondary side with a transformer. Transformer

can be used to step up or down an input voltage according to turns ratio. Besides, input-output

relation is the same as buck boost converter. Input-output relation is shown in Equation (1).

Vo =

Ns
Np

D
1 − D
Vin | (1)

Transformer is mainly used for the applications transmitting energy without storage. However,

transformer of flyback converter stores an energy, and then passes it to secondary side, which

is the reason for why flyback transformer is also called as coupled inductor. Hence,

considerations for energy stored, saturation current, inductance are important for transformer

design. The design of transformer is started with application information given in the datasheet.

Table 1 shows some system level information and controller requirements having an impact on

the transformer design.

Table 1 Parameters for the transformer design

Description | Symbol | Value
Input voltage range | Vin,min - Vin,max | 220V – 400V
Output voltage | Vo | 12V
Max. output power | Pout | 100W
Max. switching frequency | fs | 140kHz
Min. Switch off time* | tOFF(MIN) | 800ns
Min. Switch on time* | tON(MIN) | 300ns
Backup time* | tBU | 50μs

* These parameters will be explained in detail while calculating their limitations on primary

inductance.

Application information given in the datasheet determines the minimum and maximum limits

for the primary, magnetizing, inductance due to parameters given in Table 1 such as tOFF(MIN),

tON(MIN) and tBU. Before finding the limitations, the peak of the primary current should be

determined according to working principle of controller and the delivered maximum output

power. While the minimum current limit of the controller affects the limitations of primary inductance due to tOFF(MIN) and tON(MIN), the maximum output power has to be satisfied according

to magnetic energy storage shown in Equation (2).

Emag =

1
2

Li

2 | (2)

The maximum peak current in primary side can be found from the desired output power. Since

the peak current is observed at maximum power and the controller has boundary mode control,

the peak current can be calculated as seen in Equation (3). Efficiency is taken as %80 as a safety

margin due to practical considerations.

ISW(MAX) =

2Pout
ɳVinD

= 3.75A

Vin = 220V, ɳ = 0.8(Eff), Pout = 100W

(3)

### 4.1.Limitations of Primary Inductance

I. tOFF(MIN) – Minimum Switch Off Time

The feedback of the output voltage is given through the tertiary winding. The nonzero voltage

between the tertiary winding is created when the secondary current flows. The required

minimum time to sample voltage by the sample-and-hold error amplifier is 800ns. “In order to

ensure proper sampling, the secondary winding needs to conduct current for at least 800ns.”

[1] The limitation due to tOFF(MIN) is given in Equation (4).

Lm ≥

tOFF(MIN)Np

(Vo + VF

)

ISW(MIN)

= 0.11mH

Np = 8 Turns, VF = 0.7V(Diode),ISW(MIN) = 0.2 ∗ ISW(MAX) = 0.75A

(4)

II. tON(MIN) – Minimum Switch Off Time

The controller has a minimum switch on time for the sake of blanking initial switch turn-on

current spike. The current, ISW(MIN), should not be reached for tON(MIN), which creates restriction

on the selection of flyback transformer in terms of magnetizing inductance. The limitation due

to switch on time is determined in Equation (5).

Lm ≥

tON(MIN)Vin(MAX)

ISW(MIN)

= 0.16mH | (5)
III. | Power Storage Capability of the Transformer

Equation (2) shows the magnetic energy stored in an inductor for a given current and

inductance. Since the flyback transformer stores magnetic energy due to working principle of

flyback converter, the inductance of transformer should be able to store sufficient power.

Equation (6) shows the limitation of the inductance due to magnetic energy storage.

Lm ≥

2(Vo + VF

)Io(MAX)

ɳISW(MAX)

2 | fs(MAX)
= 0.14mH | (6)

IV. Backup Time

Backup timer is stimulated to avoid low output voltage levels. Backup timer turns the primary

switch on unless the secondary side diode turns off. This feature restricts the inductance value

with maximum limit. Limitation of inductance of flyback transformer due to backup time can

be seen in Equation (7).

Lm <

0.8 Np

(Vo + VF

)tBU

ISW(MAX)

= 1.08mH | (7)

### 4.2. Determination of Turns Ratio

The output voltage is lower than the input voltage level. Transformer should step down the

input voltage for reasonable values so that sensitivity of duty cycle should not be high, i.e., duty

cycle below %10 is problem for controllers. Therefore, the turns ratio should be high as much

as possible to keep duty cycle in a range between %50 and %20.

Turns ratio has also impact on breakdown voltage of semiconductors. Table 2 shows maximum

terminal voltages of the primary switch and the secondary diode. The turns ratio has reverse

effect on the semiconductors. While turns ratio, N, increases reverse voltage of the primary

switch, it reduces reverse voltage of the secondary diode.

Table 2 Relation between turns ratio and reverse voltage of the semiconductors

Semiconductor | General Formulation for Reverse Voltage
Primary switch | VDS = Vin + N(Vo + VF) + VLeakage
Secondary diode | VR = (Vin/N) + (Vo + VF)

The turns ratio is selected as 8, which keep the duty cycle between %20 and %30. Also, this

selection can be optimized value in terms of reverse voltage of semiconductors and duty cycle.

The increase in reverse voltages results in increase in switching losses and decrease in safety

margin of devices. Duty cycle of the flyback converter in a range of input voltage is shown in

Figure 2.


Figure 2 Duty cycle vs input voltage range for 8 turns ratio, N

### 4.3. Determination of the Primary Inductance

In the part 0 , 0.16mH and 1.08mH are founded as minimum and maximum limitations,

respectively. The value between the limits may probably work. However, safety margin for

each limit should be determined to eliminate unexpected practical issues. The safety region for

each limit can be taken as %25 of limiting value above and below for minimum and maximum

limits, respectively. Hence, the primary inductance value should be between 0.2mH and

0.81mH.

The boundary mode control requires variable switching frequency according to the load. When

the primary switch is on, the inductor current starts from the zero. Therefore, the frequency

relation between frequency and inductance for the same input voltage and output voltage is

obvious, which is shown in Equation (8). Since duty cycle and turns ratio is constant, switching

frequency and primary inductance are inversely proportional for the same amount of inductor

current ripple. The inductor current ripple is determined according to output power.

ΔIL,ON =

DTsVin
Lm

ΔIL,OFF =

(1 − D)Ts(Vin + N(Vo + VF)) Lm

(8)

Transition to DCM occurs as the load decreases. Duty cycle calculation in DCM can be seen

in Equation (9). Both calculations are the same except the Pout, Vo, and R relation.

D =

Vo

Vin

√2Lmfs
√R

D =

√2PoutLmfs

Vin

(9)

Supply of the input power occurs during the on time of primary switch. Therefore, the current

ripple of the inductor is directly related with the delivered power. Equation (10) shows the

inductor current ripple calculation in DCM, which shows that Lm and fs are also inversely

proportional in DCM.

ΔIL =

Vo√2
√RLmfs

(10)

According to analysis of the relation between Lm and fs, increase in Lm results in low switching

frequency, hence, low switching loss. On the other hand, boundary mode and DCM eliminate

turn-on loss of the primary switch and reverse recovery of the secondary diode. Even if the

increase in Lm can be beneficial for switching losses, the tradeoff due to increase in Lm is

increase in size of flyback transformer and increase in windings, which causes more copper and

core losses. The question that there is a relation between copper, core losses and frequency.

Actually, this type of relations are the signs of need in optimization.

After considering iterative relation between Lm and fs, the Lm, primary inductance, is chosen as

0.4mH.

### 4.4. Core Selection

Core selection is based on shape of a core, size of a core and magnetic characteristics of a

core. First, selection based on magnetic characteristics of a core is analyzed.

I. Magnetic Characteristics of Core

General approach for the selection of core type is divided into two for flyback transformer;

distributed air-gap powder cores and gapped ferrite cores. Both type of cores has advantages.

For example, ferrite cores provide a core with more permeability. On the other, distributed air-

gap powder cores may have less core loss compared to gapped ferrite cores.

Distributed air-gap powder core is selected based on magnetic characteristics, which can

stimulate an efficiency, winding area and mechanical robustness.

Powder cores are classified. These classifications are mainly based on core loss, maximum flux

density, permeability, and cost, which can be seen in Figure 3 taken from the Magnetics. Kool

Mu is selected due to optimal permeability and core loss values. Besides, Kool Mu is preferred

due to relative low prices.


Figure 3 Classification of powder cores [2]

II. | Shape of Core
| Common preference for flyback transformers is toroidal shape. The copper loss can be
| decreased with both toroidal shape and E shape according to the current situation. While
| toroidal shapes have permeability between 14μ-125μ, E shapes have maximum 90μ relative
| permeability. However, E shapes have relatively higher Ae, area. Also, the window area may
| be higher in toroids. Hence, toroidal shape is selected.

III. | Size of Core
| Size of core will be determined from available manufactured cores. Cores are researched on
| Magnetics. (https://www.mag-inc.com/) Selected cores are tested whether they satisfy limitations due to inductance, flux
| density, saturation current, fill factor. The constructed GUI on MATLAB is used to test scores.
| Constructed GUI can be seen in Figure 4.


Figure 4 The constructed GUI on MATLAB for flyback converter design

Peak current value of the primary side is calculated ISW(MAX) that equals to 3.75A with safety

margin. Safety margin is determined according to %80 efficiency of converter. The safety

margin for saturation current of a core can be taken as %10, since the efficiency creates a

sufficient safe region. Hence, minimum saturation current is 4.1A.

Kool Mu cores have 10,500 Gauss saturation level, which is approximately equal to 1 Tesla.

Since the saturation current and created maximum flux density are proportional to each other,

saturation can be checked from both created maximum flux density and peak current of the

primary side.

Copper losses are also important due to AC resistance and number of windings. The

optimization for copper losses based on core selection can be stimulated with selection of cores

with high inductance factor, AL.

Equation (11) shows the calculation of saturation current and the created maximum flux.

Isat =

BsatAe
√LmAL

Bmax =

NpIpeakμ
le

(11)

Table 3 shows the comparison of different cores. Table 3 shows the cores are in order from high

volume to low volume. Core 3 is the most suitable one for required saturation limits. Hence,

the core 3 is selected. Inductance factor would be more to decrease windings but there is no

available Kool Mu core.

Table 3 Comparison Kool Mu cores in different sizes and inductance factors

Parameters | Core 1 930 | Core 2 350 | Core 3 310
Bsat (Tesla) | 0.9 | 0.9 | 0.9
μ - Permeability | 125 | 125 | 125
AL – Inductance factor(nH/T^2) | 157 | 105 | 90
Le – eff length (mm) | 63.5 | 58.8 | 56.7
Ae – Area (mm2) | 65.4 | 38.8 | 31.7
Isat (A) | 7.42 | 5.4 | 4.76
Bmax (Tesla) | 0.47 | 0.62 | 0.69
Np (Turns) | 50.5 | 61.7 | 66.7
Ns and Nthird (Turns) | 6.3 | 7.7 | 8.3

### 4.5. Winding and Fill Factor

Maximum switching frequency of the controller LT8316 is 140kHz. However, 140kHz

switching is not observed at high load. LT8316 works in boundary mode for high load and as

load increases, switching period should be increased according to Equation (8). Thus, AC

resistance is not as much as higher at high load. Skin depth is relatively low at high voltage.

Figure 5 given in datasheet also explains the case.


Figure 5 Switching frequency vs load, LT8316

Cable diameter should not be selected according to maximum switching frequency. The

selection of cable according to maximum switching frequency may cause selection of cable

having small area so that conduction losses at high load becomes high.

Even if the most reliable option to calculate AC resistances due to skin effect and proximity

effect is finite element analysis, there are also other methods such as Dowell’s equation. These calculations will be done after simulation. Now, the skin depth is only calculated, and it can be

seen in Equation (12). Output current equals 8.3A at full load, which results in approximately

60 kHz for 320V input. Hence, we can calculate the skin effect at 60kHz switching frequency.

Besides, temperature of copper is assumed 80°C.

δ =

1

√πfsσCuμCu

= 0.296mm | (12)

When radius of a cable is selected as equal to skin depth, the whole area of the core can be used

so that there will be no excessive cable thickness. As the frequency increases, AC resistance

will increase. However, since the load will become less, copper loss can be negligible. AWG23

cable can be used for the primary side.

The current passing through the secondary side cable is eight times of the primary side current

and the frequency is the same. At full load, secondary side should be capable to sink 8.3Adc,

11Arms. Since the ampacity of AWG23 for 75°C rating at 30°C ambient is approximately 5A,

two parallel winding of AWG23 cable can be used. On the other hand, the tertiary winding can

be wound with AWG30. Since the tertiary winding is solely used to get feedback, there is a

very small current. Table 4 shows the windings details and fill factor.

Table 4 Transformer cable sizes and fill factor

| AWG | # of Turns | Copper Area
Primary | 23 | 67 | 17.3 mm²
Secondary | 23 | 8.3 x2 | 4.3 mm²
Tertiary | 30 | 8.3 | 0.83 mm²
Total | NA | 92 | 22.43 mm²
Fill Factor | 22.43mm² 139mm² = 0.16

# Simulations

After finalizing the analytical calculations, the simulation model is constructed and simulated.

For simulations we are using LTSpice since we have opted to use controllers manufactured by

Analog Devices. LTSpice is a SPICE-based analog electronic circuit simulation software that

is produced by the semiconductor manufacturer Analog Devices. It is the most widely used

distribution of the SPICE software. Here the LTC3805 and LT8316 designs have been analyzed

and the resulting waveforms have been taken. The efficiency report has been added for the

LTC3805 design but could not be done for the LT8316. Though from the simulations we

observed similar efficiency values for both.


Figure 6 LTSpice schematic for the No Opto Flyback Converter (LT8316)


Figure 7 Output voltage of converter at full load and 400V input (LT8316)


Figure 8 Voltage on the MOSFET at full load and 400V input (LT8316)

Figure 9 oltage on the Diode at full load and 400V input (LT8316)

Figure 10 Current waveforms of the transformer’s primary at full load and 400V input (LT8316)


Figure 11 Current waveforms of the transformer’s secondary at full load and 400V input (LT8316)

Figure 12 Output voltage of converter at 10% load and 220V input (LT8316)

Figure 13 Voltage on the MOSFET at 10% load and 220V input (LT8316)


Figure 14 Voltage on the Diode at 10% load and 220V input (LT8316)

Figure 15 Current waveforms of the transformer’s primary at 10% load and 220V input (LT8316)

Figure 16 Current waveforms of the transformer’s secondary at 10% load and 220V input (LT8316)


Figure 17 LTSpice schematic for the Flyback Converter with Opto (LTC3805)

Figure 18 Output voltage of converter at full load and 400V input (LTC3805)


Figure 19 Voltage on the MOSFET at full load and 400V input (LTC3805)

Figure 20 Voltage on the Diode at full load and 400V input (LTC3805)

Figure 21 Current waveforms of the transformer’s primary and secondary at full load and 400V input (LTC3805)


Figure 22 Efficiency report from LTSpice for the full load 400V input case (LTC3805)

Figure 23 Output voltage of converter at 10% load and 220V input (LTC3805)


Figure 24 Voltage on the MOSFET at 10% load and 220V input (LTC3805)

Figure 25 Voltage on the Diode at 10% load and 220V input (LTC3805)


Figure 26 Current waveforms of the transformer’s primary and secondary at 10% load and 220V input (LTC3805)

Figure 27 Efficiency report from LTSpice for the 10% load 220V input case (LTC3805)

Simulation results for both LTC3805 and LT8316 are given above. As seen in the results, both

designs satisfy the project requirements for both full load and light load cases. However,

LT8316 provides a simpler design.

# Component Selection

After simulating the circuit with LT8316, power components are selected. Although all the

control and auxiliary components need to be selected at the end of the project, only the power

components are considered yet. Because most of the cost and parasitic effects come from the

power elements.

First, power MOSFET is selected according to the simulation results. At full load, peak voltage

between drain and source terminals are approximately 630 V and peak current through the drain

terminal is 3A. These values are considered while determining the ratings of the MOSFET.

Controller IC can provide switching frequency up to 140kHz, which can create a high switching

loss and thermal dissipation. By considering all the limitations above and adding some safety

margin, IPA70R600P7S CoolMOS Power MOSFET is selected. Table below shows the ratings

of this MOSFET. Detailed datasheet can be found in the Github repository.

Table 5 MOSFET parameters

VDS | 700 V
RDS(ON) | 0.6 Ω
ID,max | 20 A
Qg | 10.5 nC

Second, the secondary diode is selected. According to the simulation results, peak voltage on

the diode is approximately 85V and peak current is approximately 25A. Since this diode can

create a large switching loss, a schottky diode is preferred instead of a minority carrier diode.

By considering these limitations, SS10PH9 Schottky diode which is manufactured by Vishay

Semiconductor is selected. Table below shows the diode ratings.

Table 6 Diode Parameters

VR | 100 V
IF,average | 10 A
IF,peak | 200 A
VF | 0.661 V

After the switches, output capacitors are selected. There are two different types of capacitors at

the output: 22uF and 470uF. Since the 22uF capacitors will most probably have a small ESR

and be cheap, they will be selected later. For now, only the 470uF capacitors are selected.

Output voltage is 12V. Capacitance and voltage ratings are considered with some safety margin

while selecting the capacitors. Therefore, A750EQ477M1CAAE015 capacitors that are

produced by KEMET are selected. Table below shows the ratings of these capacitors.

Table 7 Output Capacitor Ratings

VDC | 16 V

C 470 uF

ESR @100kHz | 15 mΩ

Note that the LT8316 controls the circuit with variable frequency. As the switching frequency

changes, impedances of capacitors may vary and for some high frequencies, they can even lose

their capacitive characteristics and behave like a resistance or an inductor. To guarantee that

the capacitors keep their characteristics, frequency analysis must be done. Most probably there

will not be any problem. However, such an analysis is going to be conducted in the final report

for reliability.

At the output of the converter, a CLC filter is used instead of a simple capacitor. For this filter,

an inductor with 600nH inductance is required. According to the simulation results, peak

current through this inductor is 24A and average current is 8.33A. These ratings are considered while selecting the inductor. ASPIAIG-F7030-R60 is chosen at the end. Table below shows the

ratings of the inductor.

Table 8 Inductor Ratings

L | 600 nH

R 3.2 mΩ

Saturation Current | 32 A
Temperature Rise Current | 23 A

To decrease the cost, the inductor may be designed instead of just buying it. This option will be

considered after the feedback.

Finally, clamper circuit diodes are selected. Note that there is a schottky diode at the bias pin

of the controller and snubbers for the MOSFET and secondary diodes. Since these parts face

less stress than the ones are discussed here, they are selected in the future. In the clamper circuit,

two zener (in series) and one normal diode are used. During the simulations, voltage and current

stress on them are observed and selections are made according to the measurements.

RFN1L7SSD is selected for the minority carrier diode and 1N5378B is selected for the zener

diodes. Tables below show their ratings.

Table 9 Diode Ratings

Repetitive Peak Rev. Voltage | 700 V
Average Current | 0.8 A
Non-Rep. Surge Current | 15 A
Reverse Recovery Time | 45 ns

Table 10 Zener Diode Ratings

Zener Voltage | 105 V
Max. Steady State Power Dissipation | 5 W
Non-Rep. Surge Current | 1.5 A

After selecting some important components, a cost table is constructed to project the total cost

and make changes in the elements if needed.

Table 11 Cost of Selected Components

Component | Unit Cost ($)
IPA70R600P7S CoolMOS Power MOSFET | 0.47
SS10PH9 Schottky diode | 0.39
A750EQ477M1CAAE015 Capacitor | 0.16
ASPIAIG-F7030-R60 Inductor | 0.86
RFN1L7SSD Diode | 0.2
1N5378B Zener Diode | 0.14
LT8316 Controller | 3.35
Total | 5.57

# Conclusion

Flyback topology is selected to implement isolated DC/DC converter from variable input

voltage range (220V-400V) to 12V output with 100W output power. Advantages due to low

size with single inductor and popularity are the parameters to select Flyback topology.

LT8316 is selected among some other alternative controllers such as PowiGan - InnoSwitch3-

EP by Power Integrations, which is restricted by requirement of controller simulation. Since

Analog Devices has LTSpice models of controllers, LT8316 is easily implemented on the

simulation tool.

Determination of the topology and the controller have took us to design the transformer and

clamp circuit, select semiconductor and output filter. Clamp circuits and semiconductor

ratings depends on each other and they have been selected with that consideration. On the

other hand, even if the transformer design have rule of thumbs and requirements, there is a

huge gap for optimization in terms of core loss, copper loss and size. Thus, selection of turns

ratio, primary inductance and winding have been explained in detail.

Finally, simulation report will be enhanced with further improvents on efficiency, thermal

simulations and PCB design. Also, constructed GUI shown in Figure xxx will be used to

optimize the converter in terms of efficiency, size and cost.

# References

[1] Analog Devices LT8316 Datasheet

https://www.analog.com/media/en/technical-documentation/data-sheets/lt8316.pdf

[2] Magnetics – Kool Mu cores properties

https://www.mag-inc.com/Products/Powder-Cores

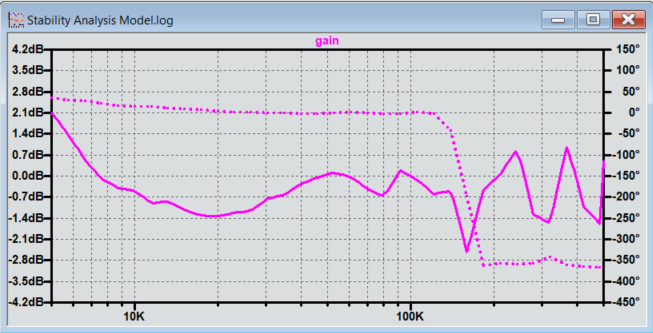
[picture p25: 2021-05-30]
Stability/bode plot 10m.png

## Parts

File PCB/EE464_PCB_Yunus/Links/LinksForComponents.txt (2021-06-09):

Resistor - R_Tc - Temperature Comp - 110k - 1/10W
https://www.digikey.com/en/products/detail/vishay-dale/CRCW0603110KJNEA/1174278

Resistor - R_FB1 - Feedback - 48.7k - 1/10W
https://www.digikey.com/en/products/detail/vishay-dale/CRCW060348K7FKEA/1174860

Resistor - R_FB2 - Feedback - 5.36k - 1/10W
https://www.digikey.com/en/products/detail/vishay-dale/CRCW06035K36FKEA/1174751

Resistor - R_Sense - Sense - 20m - 1/4W
https://www.digikey.com/en/products/detail/susumu/RL1220T-R020-J/714251

Resistor - R_IREG//SS - Current Regulation and SoftStart - 60.4k - 1/10W
https://www.digikey.com/en/products/detail/vishay-dale/CRCW060360K4FKEA/1174871

Resistor - R_CVc - Loop Compensation - 20k - 1/10W
https://www.digikey.com/en/products/detail/vishay-dale/CRCW060320K0FKEAC/7928409

Resistor - R_DCM - DCM Detection - 9.76k - 1/10W
https://www.digikey.com/en/products/detail/vishay-dale/CRCW06039K76FKEA/1174781

Resistor - R_Pri_Snubber - Snubber - 500 - 2W
https://www.digikey.com/en/products/detail/bourns-inc/CRM2512-FX-4990ELF/4698401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

Resistor - R_Sec_Snubber - Snubber - 50 - 1/3W
https://www.digikey.com/en/products/detail/vishay-dale/CRCW060349R9FKEAHP/2222241

Capacitor - CVc - Loop Compensation - 100nF - 25V
https://www.digikey.com/en/products/detail/murata-electronics/GRM155R71E104KE14J/4905174

Capacitor - CİNTVc - Initial Bias - 4.7uF - 25V
https://www.digikey.com/en/products/detail/murata-electronics/GRM219R61E475MA73D/4905428

Capacitor - CBias - Bias - 4.7uF - 35V
https://www.digikey.com/en/products/detail/murata-electronics/GRM219R6YA475KA73D/3900501

Capacitor - CDCM - DCM Detection Pin - 47pF - 100V
https://www.digikey.com/en/products/detail/murata-electronics/GRM1885C2A470JA01D/586980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

Capacitor - C_Out - Output Capacitor - 470uF - 16V
https://www.digikey.com/en/products/detail/kemet/A750EQ477M1CAAE015/13420057

Capacitor - C_Out - Output Capacitor - 10uF - 25V
https://www.digikey.com/en/products/detail/murata-electronics/GRM21BR61E106MA73L/4905533

Capacitor - C_Pri_Snub - Primary Snubber Capacitor - 100p - 630V
https://www.digikey.com/en/products/detail/murata-electronics/GRM31A5C2J101JW01D/2039000

Capacitor - C_Sec_Snub - Primary Snubber Capacitor - 470p - 100V
https://www.digikey.com/en/products/detail/murata-electronics/GRM155R72A471KA01D/2610965

Ferrite core - ETD 34 x 17 x 11 - 1mm Air gap
https://www.digikey.com/en/products/detail/epcos-tdk-electronics/B66361G1000X127/3915590

Coil former (Karkas) - ETD 34 x 17 x 11 - Horizontal
https://www.digikey.com/en/products/detail/epcos-tdk-electronics/B66362W1014T001/3914807

LT8316 - IC - LT8316IFE#PBF
https://www.digikey.com/en/products/detail/analog-devices-inc/LT8316IFE-PBF/9972964

Secondary diode - STPS20SM120ST - TO220-AB
https://www.digikey.com/en/products/detail/stmicroelectronics/STPS20SM120ST/5244936

MOSFET - IPA70R600P7S - Infinion
https://www.digikey.com/en/products/detail/infineon-technologies/IPA70R600P7SXKSA1/6579136

Diode - Clamp Fast Diode - RFN1L7S - 700V
https://www.digikey.com/en/products/detail/rohm-semiconductor/RFN1L7SDDTE25/12359526

Diode Zener - Clamp Zener Diode - 1N5378 - 100V - 5W
https://www.digikey.com/en/products/detail/on-semiconductor/1N5378BG/1474165

Diode - Bias - RB058L150 - 150V 3A
https://www.digikey.com/en/products/detail/rohm-semiconductor/RB058LAM150TR/7243289

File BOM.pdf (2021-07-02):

Comment | Description | Designator | Quantity | Supplier Order Qty 1Supplier Unit Price 1Total Cost/Board | Cost for 1000 boards
4.7uF | CAP CER 4.7UF 25V X5R 0805 GRM219R61E475MA7 3D, CAP CER 4.7UF 35V 10% X5R 0805 GRM219R6YA475KA73 D, 4.7µF ±10% 10V X7R Ceramic Capacitor -55°C ~ 125°C Surface Mount, MLCC 0805 (2012 Metric) 0.079" L x 0.049" W (2.00mm x 1.25mm) | C1, C5, C13 | 3 | 3000 | 0,05951 | 0,17853 | 178,53
100nF | CAP CER 0.1UF 25V X7R 0402 GRM155R71E104KE14J | C2 | 1 | 1000 | 0,00696 | 0,00696 | 6,96
0.15uF | CAP CER 0.15UF 500V X7R 1210 C1210C154KCRACTU | C3, C4, C15 | 3 | 3000 | 0,14268 | 0,42804 | 428,04
47pF | MURATA - GRM1885C2A470JA01D - SMD Multilayer Ceramic Capacitor, 47 pF, 100 V, 0603 [1608 Metric], ± 5%, C0G / NP0, GRM Series C6 | | 1 | 1000 | 0,02178 | 0,02178 | 21,78
470u | Solid Polymer Aluminum, Radial, Output Capacitor A750EQ477M1CAAE01 5 | C7, C8 | 2
10u | MURATA - GRM21BR61E106MA73L - SMD Multilayer Ceramic Capacitor, 10 µF, 25 V, 0805 [2012 Metric], ± 20%, X5R, GRM Series C9 | | 1 | 1000 | 0,06279 | 0,06279 | 62,79
100p | CAP CER 100PF 630V C0G/NP0 1206 GRM31A5C2J101JW01 D | C10 | 1 | 1000 | 0,12665 | 0,12665 | 126,65
1uF | Cap Ceramic 1uF 16V X5R 10% SMD 1206 85°C T/R C11 | | 1 | 1000 | 0,14662 | 0,14662 | 146,62
470p | Cap Ceramic 470pF 100V X7R 10% SMD 0402 125C Paper T/R GRM155R72A471KA01 D | C12 | 1 | 1000 | 0,01328 | 0,01328 | 13,28
1500pF | Ceramic Suppression Cap, 1500PF, X1/Y1 Rohs Compliant: Yes C14 | | 1
TVS | TVS DIODE 376VWM 602VC SMD D1 | | 1 | 1000 | 0,25955 | 0,25955 | 259,55
RB058L150 | Schottky Barrier Diode for general rectification Diode for Bias Pin D2 | | 1 | 1000 | 0,11154 | 0,11154 | 111,54
3SMAJ5949B | DIODE ZENER 100V 3W DO214AC 3SMAJ5949B-TPMSCT-ND | D3, D4, D5 | 3 | 3000 | 0,1452 | 0,4356 | 435,6
RFN1L7S | Clamp circuit fast diode D6 | | 1
VIN+ | TERM TURRET SINGLE L=5.56MM TIN 2501-2-00-80-00-00-07-0 | E1 | 1 | 1000 | 0,07986 | 0,07986 | 79,86
VIN- | TERM TURRET SINGLE L=5.56MM TIN 2501-2-00-80-00-00-07-0 | E2 | 1 | 1000 | 0,07986 | 0,07986 | 79,86
VOUT+ | TERM TURRET SINGLE L=5.56MM TIN 2501-2-00-80-00-00-07-0 | E3 | 1 | 1000 | 0,07986 | 0,07986 | 79,86
VOUT- | TERM TURRET SINGLE L=5.56MM TIN 2501-2-00-80-00-00-07-0 | E4 | 1 | 1000 | 0,07986 | 0,07986 | 79,86
Fuse | FUSE CLIP CARTRIDGE 10A PCB 0751.0110 | F1 | 1 | 1000 | 0,06384 | 0,06384 | 63,84
IPA70R600P7S | Single N-Channel 700V 600 mOhm 10.5 nC CoolMOS Q1 | | 1 | 1000 | 0,5404 | 0,5404 | 540,4
Sec. | INFINEON - BSC040N10NS5ATMA1 - MOSFET, N-KANAL, 100V, 100A, TDSON Q2 | | 1 | 1000 | 1,75 | 1,75 | 1750
20k | D11/CRCW0603-C 100 20K 1% ET1 CRCW060320K0FKEAC | R1 | 1 | 1000 | 0,00652 | 0,00652 | 6,52
60.4k | VISHAY - CRCW060360K4FKEA - SMD Chip Resistor, 0603 [1608 Metric], 60.4 kohm, CRCW e3 Series, 75 V, Thick Film, 100 mW R2 | | 1 | 1000 | 0,00701 | 0,00701 | 7,01
48.7k | Res Thick Film 0603 48.7K Ohm 1% 0.1W(1/10W) ±100ppm/C Pad SMD Automotive T/R CRCW060348K7FKEA | R3 | 1 | 1000 | 0,00701 | 0,00701 | 7,01
9.76k | Vishay CRCW Series Thick Film Surface Mount Resistor 0603 Case 9.76k 1% 0.1W 100ppm/K CRCW06039K76FKEA | R4 | 1 | 1000 | 0,00701 | 0,00701 | 7,01
110k | RES SMD 110K OHM 5% 1/10W 0603 CRCW0603110KJNEA | R5 | 1 | 1000 | 0,0061 | 0,0061 | 6,1
5.36k | VISHAY CRCW06035K36FKEA. | SMD Chip Resistor, Thick Film, 5.36 kohm, 75 V, 0603 [1608 Metric], 100 mW, 1%, CRCW Series R6 | 1 | 1000 | 0,00701 | 0,00701 | 7,01
4.7ohm | RES SMD 4.7 OHM 5% 1/10W 0603 R7 | | 1 | 1000 | 0,00396 | 0,00396 | 3,96
2.32k | RES SMD 2.32K OHM 1% 1/10W 0603 R8 | | 1 | 1000 | 0,00305 | 0,00305 | 3,05
500 | Res Thick Film 2512 499 Ohm 1% 2W ±100ppm/°C Molded SMD SMD Paper T/R CRM2512-FX-4990ELF | R9 | 1 | 1000 | 0,12558 | 0,12558 | 125,58
50 | Vishay CRCW Series Thick Film Power Resistor 0603 Case 49.9 1% 0.25W 100ppm/K CRCW060349R9FKEAH P | R10 | 1 | 1000 | 0,02422 | 0,02422 | 24,22
20m | TR / Current Sensors, 0805 0.25W, 5% RL1220T-R020-J | R11 | 1 | 1000 | 0,04914 | 0,04914 | 49,14
ETD34 | Epcos B66362W1014T001 ETD 34 Coil Former, 14 Pins B66362W1014T001 | T1 | 1 | 1000 | 0,96782 | 0,96782 | 967,82
U_LT8316EFE#PBF | DC/DC Cntrlr Single-OUT 142kHz Automotive 16-Pin TSSOP EP Tube U1 | | 1 | 1000 | 3,42 | 3,42 | 3415,5
LT8309 | IC REG FLYBACK ISO ADJ TSOT23-5 U2 | | 1 | 1000 | 3,43 | 3,43 | 3431,76
12,52945 | 12526,71

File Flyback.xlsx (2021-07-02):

Comment | Description | Designator | Quantity | Supplier Order Qty 1 | Supplier Unit Price 1 | Total Cost/Board | Cost for 1000 boards
4.7uF | CAP CER 4.7UF 25V X5R 0805 CAP CER 4.7UF 35V 10% X5R 0805 4.7µF ±10% 10V X7R Ceramic Capacitor | C1, C5, C13 | 3 | 3000 | 0.05951 | 0.17853 | 178.53
100nF | CAP CER 0.1UF 25V X7R 0402 | C2 | 1 | 1000 | 0.00696 | 0.00696 | 6.96
0.15uF | CAP CER 0.15UF 500V X7R 1210 | C3, C4, C15 | 3 | 3000 | 0.14268 | 0.42804 | 428.04
47pF | MURATA SMD Multilayer Ceramic Capacitor, 47 pF, 100 V, ± 5%, C0G / NP0 | C6 | 1 | 1000 | 0.02178 | 0.02178 | 21.78
470u | Solid Polymer Aluminum, Radial, Output Capacitor | C7, C8 | 2 | 2000 | 0.23132 | 0.69396 | 693.96
10u | MURATA SMD Multilayer Ceramic Capacitor, 10 µF, 25 V, ± 20%, X5R | C9 | 1 | 1000 | 0.06279 | 0.06279 | 62.79
100p | CAP CER 100PF 630V C0G/NP0 1206 | C10 | 1 | 1000 | 0.12665 | 0.12665 | 126.65
1uF | Cap Ceramic 1uF 16V X5R 10% SMD 1206 85°C T/R | C11 | 1 | 1000 | 0.14662 | 0.14662 | 146.62
470p | Cap Ceramic 470pF 100V X7R 10% SMD 0402 125C | C12 | 1 | 1000 | 0.01328 | 0.01328 | 13.28
1500pF | Ceramic Suppression Cap, 1500PF, X1/Y1 Rohs Compliant: Yes | C14 | 1 | 1000 | 0.6545 | 0.6545 | 654.5
TVS | TVS DIODE 376VWM 602VC SMD | D1 | 1 | 1000 | 0.25955 | 0.25955 | 259.55
RB058L150 | Schottky Barrier Diode for general rectification Diode for Bias Pin | D2 | 1 | 1000 | 0.11154 | 0.11154 | 111.54
3SMAJ5949B | DIODE ZENER 100V 3W DO214AC | D3, D4, D5 | 3 | 3000 | 0.1452 | 0.4356 | 435.6
RFN1L7S | Clamp circuit fast diode | D6 | 1 | 1000 | 0.1366 | 0.1366 | 136.6
VIN+ | TERM TURRET SINGLE L=5.56MM TIN | E1 | 1 | 1000 | 0.07986 | 0.07986 | 79.86
VIN- | TERM TURRET SINGLE L=5.56MM TIN | E2 | 1 | 1000 | 0.07986 | 0.07986 | 79.86
VOUT+ | TERM TURRET SINGLE L=5.56MM TIN | E3 | 1 | 1000 | 0.07986 | 0.07986 | 79.86
VOUT- | TERM TURRET SINGLE L=5.56MM TIN | E4 | 1 | 1000 | 0.07986 | 0.07986 | 79.86
Fuse | FUSE CLIP CARTRIDGE 10A PCB | F1 | 1 | 1000 | 0.06384 | 0.06384 | 63.84
IPA70R600P7S | Single N-Channel 700V 600 mOhm 10.5 nC CoolMOS Power Mosfet - TO-220-3FP | Q1 | 1 | 1000 | 0.5404 | 0.5404 | 540.4
Sec. | INFINEON - BSC040N10NS5ATMA1 - MOSFET, N-KANAL, 100V, 100A, TDSON | Q2 | 1 | 1000 | 1.75 | 1.75 | 1750
20k | D11/CRCW0603-C 100 20K 1% ET1 | R1 | 1 | 1000 | 0.00652 | 0.00652 | 6.52
60.4k | VISHAY - CRCW060360K4FKEA - SMD Chip Resistor, 60.4 kohm | R2 | 1 | 1000 | 0.00701 | 0.00701 | 7.01
48.7k | Res Thick Film 0603 48.7K Ohm 1% 0.1W(1/10W) | R3 | 1 | 1000 | 0.00701 | 0.00701 | 7.01
9.76k | Vishay CRCW Series Thick Film Surface Mount Resistor 9.76k 1% 0.1W | R4 | 1 | 1000 | 0.00701 | 0.00701 | 7.01
110k | RES SMD 110K OHM 5% 1/10W 0603 | R5 | 1 | 1000 | 0.0061 | 0.0061 | 6.1
5.36k | VISHAY SMD Chip Resistor, Thick Film, 5.36 kohm, 75 V, 100 mW, 1% | R6 | 1 | 1000 | 0.00701 | 0.00701 | 7.01
4.7ohm | RES SMD 4.7 OHM 5% 1/10W 0603 | R7 | 1 | 1000 | 0.00396 | 0.00396 | 3.96
2.32k | RES SMD 2.32K OHM 1% 1/10W 0603 | R8 | 1 | 1000 | 0.00305 | 0.00305 | 3.05
500ohm | Res Thick Film 2512 499 Ohm 1% 2W ±100ppm/°C Molded SMD | R9 | 1 | 1000 | 0.12558 | 0.12558 | 125.58
50ohm | Vishay CRCW Series Thick Film Power Resistor 0603 1% 0.25W | R10 | 1 | 1000 | 0.02422 | 0.02422 | 24.22
20m | TR / Current Sensors, 0805 0.25W, 5% | R11 | 1 | 1000 | 0.04914 | 0.04914 | 49.14
ETD34 | Epcos B66362W1014T001 ETD 34 Coil Former, 14 Pins | T1 | 1 | 1000 | 0.96782 | 0.96782 | 967.82
LT8316 | DC/DC Cntrlr Single-OUT 142kHz Automotive 16-Pin TSSOP EP Tube | U1 | 1 | 1000 | 3.42 | 3.42 | 3415.5
LT8309 | IC REG FLYBACK ISO ADJ TSOT23-5 | U2 | 1 | 1000 | 3.43 | 3.43 | 3431.76
ETD34 | FERRITE CORE ETD N87 1PC | T1 | 2 | 2000 | 0.72541 | 1.45081 | 1450.81
AWG28 | ESSEX MAGNET WIRE 28 AWG GAUGE ENAMELED 10LBS | T1 |  | 5 | 142 | 0.71 | 710
PCB | 96.00x63.00mm 2 layer 2oz copper 1.6mm |  | 1 | 1000 | 0.976 | 0.976 | 976
Case | PR-120 |  | 1 | 1000 | 1.69 | 1.69 | 1690
 |  |  |  |  |  | 18.84132 | 18838.58

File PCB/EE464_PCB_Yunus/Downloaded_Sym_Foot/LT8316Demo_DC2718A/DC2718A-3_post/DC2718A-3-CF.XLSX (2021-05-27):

Item | Qty | Reference | Part Description | Manufacturer / Part #
 |  |  | REQUIRED CIRCUIT COMPONENTS:
1 | 1 | C2 | CAP., FILM 1.0uF, 5% ,630V, RADIAL | PANASONIC, ECWFG2J105P1
2 | 1 | C3 | CAP., X5R, 4.7uF, 25V, 10%, 0805 | MURATA, GRM219R61E475KA73D
3 | 1 | C4 | CAP., NP0, 47pF, 100V, 5%, 0603 | MURATA, GRM1885C2A470JA01J
4 | 1 | C6 | CAP., X5R, 100nF, 25V, 10%, 0603 | MURATA, GRM188R61E104KA01D
5 | 1 | C7 | CAP., X7R, 47pF, 25V, 10%, 0603 | AVX, 06033C470KAT2A
6 | 2 | C8,C14 | CAP., X7R, 100nF, 630V,10%,1812 | MURATA,GRM43DR72J104KW01L
7 | 1 | C9 | CAP.,X7S, 4.7uF, 50V,10%, 0805 | MURATA, GRM21BC71H475KE11L
8 | 1 | C10 | Cap., Y5U 2200pF 400VAC 20% | VISHAY, 440LD22-R
9 | 3 | C11,C15,C23 | CAP., X5R, 47uF,16V,10%,1210 | MURATA, GRM32ER61C476KE15K
10 | 1 | C12 | CAP., ALUM.,470uF, 25V, 20% | PANASONIC, EEHZK1E471P
11 | 1 | C13 | CAP., C0G, 1nF, 25V, 5%, 0603 | MURATA, GRM1885C1E102JA01D
12 | 1 | D1 | DIODE, ZENER, 13V,1.5W SMA | CENTRAL SEMI.,CMZ5928B TR13
13 | 1 | D2 | DIODE, 150V, SOD323 | DIODES INC., BAV20WS-7-F
14 | 1 | D3 | DIODE, 1KV, 1A, SOD123FA | ON SEMI., US1MFA
15 | 1 | D4 | DIODE, TVS, 188V, SMB | VISHAY., SMBJ188A-E3/52
16 | 1 | D5 | DIODE, SCHOTTKY, 20A, 120V, TO-277 | FAIRCHILD, FSV20120V
17 | 1 | Q2 | N-CH MOSFET, 900V, 6A, DPAK | ST, STD6N90K5
18 | 1 | R1 | RES., CHIP, 10 OHM, 1/10W, 1% 0603 | VISHAY, CRCW060310R0FKEA
19 | 1 | R2 | RES., CHIP,56.2k, 1/10W, 1% 0603 | VISHAY,CRCW060356K2FKEA
20 | 2 | R3,R6 | RES., CHIP, 10k, 1/10W, 1% 0603 | VISHAY, CRCW060310K0FKEA
21 | 3 | R4,R14,R15 | RES., CHIP, 499K, 1/4W, 1% 1206 | VISHAY, CRCW1206499KFKEA
22 | 1 | R5 | RES., CHIP, 20K, 1/10W, 1% 0603 | VISHAY, CRCW060320K0FKEA
23 | 1 | R7 | RES., SENSE, 0.05 OHM , 1W, 1% 0805 | SUSUMU, KRL2012D-M-R050-F-T5
24 | 1 | R8 | RES., CHIP, 121K, 1/10W, 1% 0603 | VISHAY,CRCW0603121KFKEA
25 | 1 | R9 | RES., CHIP, 44.2k, 1/10W, 1% 0603 | VISHAY,CRCW060344K2FKEA
26 | 1 | R10 | RES., CHIP, 4.99k, 1/10W, 1% 0603 | VISHAY, CRCW06034K99FKEA
27 | 1 | R12 | RES., 100 OHM,1/10W, 1% 0603 | VISHAY, CRCW0603100RFKEA
28 | 1 | R13 | RES., 20 OHM,1/10W, 1% 0603 | VISHAY, CRCW060320R0FKEA
29 | 1 | T1 | TRANSFORMER | SUMIDA, 11328-T078
 |  | T1 ( ALTERNATED) | TRANSFORMER | Wurth Elektronik, 750317589
30 | 1 | U1 | I.C., LT8316EFE, TSSOP20FE(16) | ANALOG DEVICES, LT8316EFE#PBF
 |  |  | ADDITIONAL DEMO BOARD CIRCUIT COMPONENTS:
1 | 0 | C16 (OPT) | CAP.,0603
2 | 0 | R11(OPT) | RES.,1206
3 | 0 | R16 (OPT) | RES., 0603
 |  | HARDWARE-FOR DEMO BOARD ONLY:
1 | 4 | E1-E4 | TESTPOINT, TURRET, .094" pbf | MILL-MAX, 2501-2-00-80-00-00-07-0
2 | 4 | MH1-MH4 | STAND-OFF, NYLON 0.25" | Wurth Elektronik, 702931000
3 | 1 | JP1 | HEADER 3 PIN 0.079 SINGLE ROW | Wurth Elektronik, 62000311121
4 | 1 | XJP1 | SHUNT, .079" CENTER | Wurth Elektronik, 60800213421
5 | 1 |  | FAB, PRINTED CIRCUIT BOARD | DEMO CIRCUIT 2718A
6 | 1 |  | STENCIL FOR TOP | STENCIL DC2718A

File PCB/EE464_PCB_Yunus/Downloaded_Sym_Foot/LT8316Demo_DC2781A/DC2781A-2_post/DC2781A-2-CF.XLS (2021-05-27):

Item | Qty | Reference | Part Description | Manufacturer / Part #
 |  | REQUIRED CIRCUIT COMPONENTS:
1 | 1 | C1 | CAP., 0.1uF, X7R, 630V, 10%, 1812 | MURATA , GRM43DR72J104KW01L
2 | 1 | C3 | CAP., 10uF, X5R, 25V, 20%, 0603 | MURATA, GRM188R61E106MA73D
3 | 1 | C4 | CAP., 10pF, C0G, 630V, 5%, 1206 | MURATA, GRM31A5C2J100JW01D
4 | 2 | C5,C10 | CAP., 0.1uF, X7R, 25V, 10%, 0603 | MURATA, GRM188R71E104KA01D
5 | 1 | C8 | CAP., 10uF, X7R, 25V, 10%, 1206 | MURATA, GRM31CR71E106KA12L
6 | 3 | C11,C12,C13 | CAP., 47uF, X5R, 16V, 10%, 1210 | MURATA, GRM32ER61C476KE15K
7 | 1 | D1 | DIODE, ZENER, 13V, SOD-123 | CENTRAL SEMI., CMHZ4107 TR
8 | 1 | D2,D3 | DIODE RECTIFIER 800V, 1A, SOD-123FA | FAIRCHILD, US1KFA
9 | 1 | D4 | DIODE SCHOTTKY, 30V, 200MA, SOD323 | CENTRAL SEMI., CMDSH2-3 TR
10 | 1 | L1 | INDUCTOR, 1000uH, RTP129 | SUMIDA, RPT129NP-102MB
11 | 1 | Q1 | MOSFET, DPAK | TOSHIBA, TK3P80E
12 | 1 | R1 | RES., CHIP, 0.22 OHM, 0.2W, 1%, RL0816 | SUSUMU, RL0816S-R22-F
13 | 1 | R2 | RES., CHIP, 2.49K,1/10W, 1%, 0603 | VISHAY, CRCW06032K49FKEA
14 | 1 | R3 | RES., CHIP, 10K, 1/4W, 1%, 1206 | VISHAY, CRCW120610K0FKEA
15 | 1 | R4 | RES., CHIP, 22.1k, 1/10W , 1%, 0603 | VISHAY, CRCW060322K1FKEA
16 | 1 | R5 | RES., CHIP, 21.5K, 1/10W, 1%, 0603 | PANASONIC, ERJ-3EKF2152V
17 | 1 | U1 | I.C., LT8316EFE | ANALOG DEVICES, LT8316EFE#PBF
 |  |  | ADDITIONAL DEMO BOARD CIRCUIT COMPONENTS:
1 | 0 | C2 (OPT) | CAP., MKP338 2 X2, 8 X10
 |  | HARDWARE-FOR DEMO BOARD ONLY:
1 | 4 | E1-E4 | TESTPOINT, TURRET, .094" pbf | MILL MAX, 2501-2-00-80-00-00-07-0
2 | 4 | MH1-MH4 | STANDOFF, NYLON, 0.25" | KEYSTONE, 8831 (SNAP ON)
3 | 1 | JP1 | HEADER, 3X1 PIN, 0.079", SINGLE ROW | WURTH ELECTRONIK, 62000311121
4 | 1 | XJP1 | SHUNT, .079" CENTER | WURTH ELECTRONIK, 60800213421
5 | 1 |  | FAB, PRINTED CIRCUIT BOARD | DC2781A
6 | 1 |  | STENCIL FOR TOP | STENCIL FOR DC2781A

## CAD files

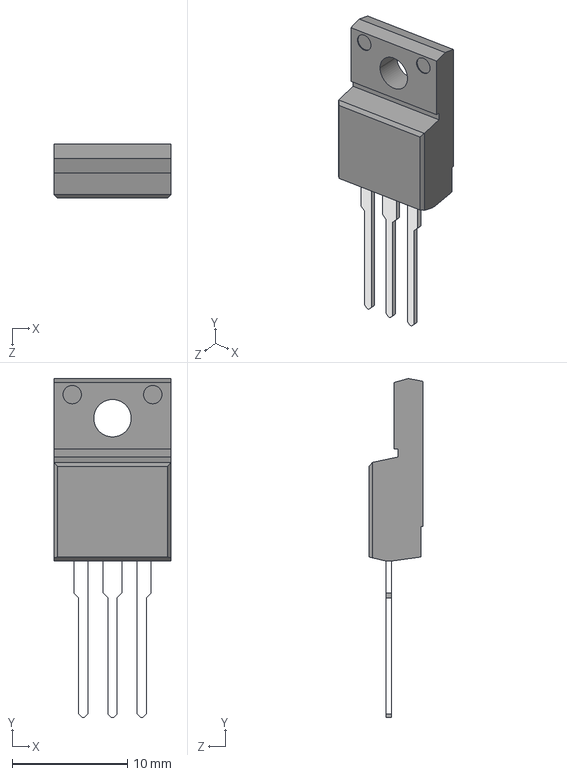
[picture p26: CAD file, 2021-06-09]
PCB/EE464_PCB_Yunus/Downloaded_Sym_Foot/TO220 FullPAK/User Library-Transistors TO-220 FULLPAK 3-PIN.step
10.2 x 29.5 x 4.70 mm

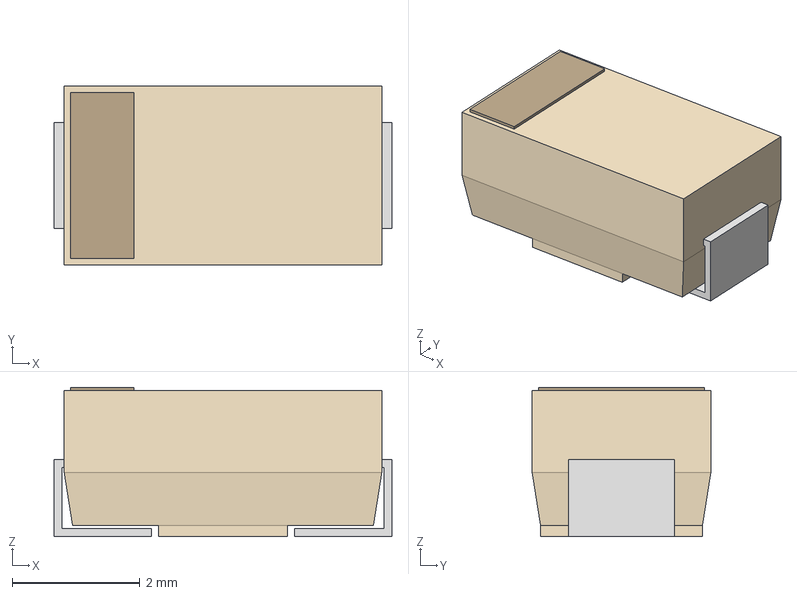
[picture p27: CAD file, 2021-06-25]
parts selection/Protection/P4SMASeries_LTF.step
5.28 x 2.79 x 2.34 mm

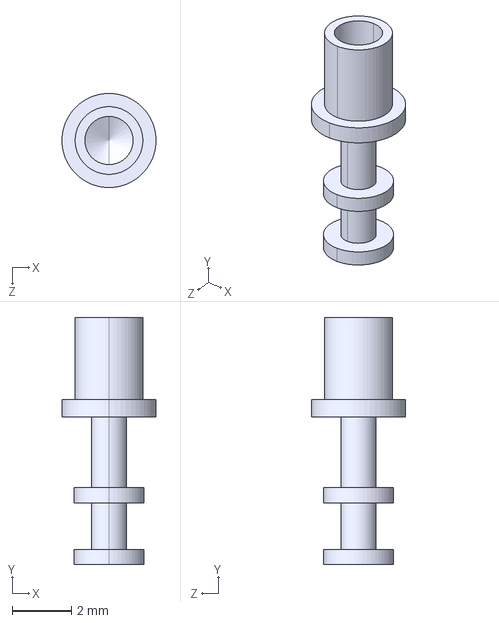
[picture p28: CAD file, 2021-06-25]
PCB/EE464_PCB_Updated/Downloaded_Sym_Foot/Connectors/2501-2-00-80-00-00-07-0--3DModel-STEP-56544.STEP
3.17 x 8.33 x 3.17 mm

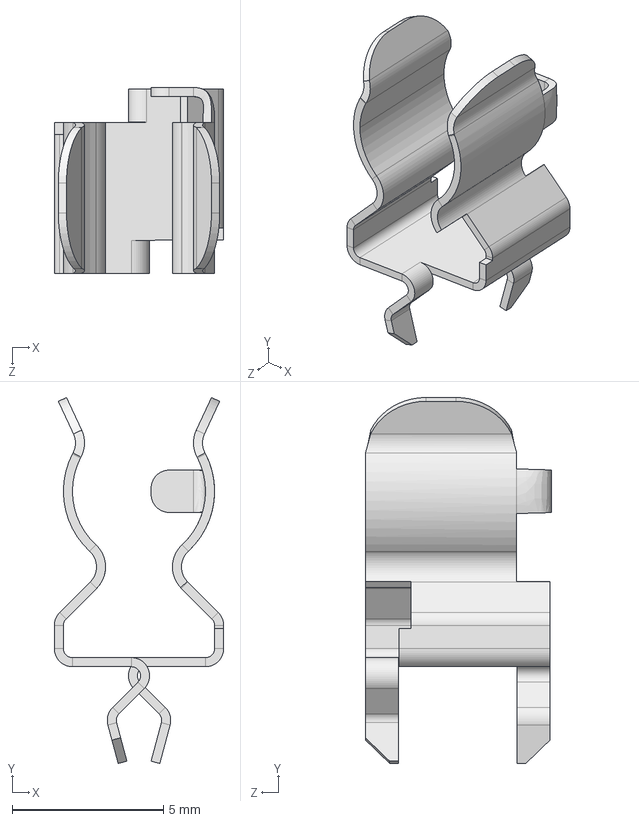
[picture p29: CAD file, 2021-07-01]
PCB/EE464_PCB_Updated/Downloaded_Sym_Foot/Fuseholder/0751.0110_1.STEP
5.60 x 12.1 x 6.15 mm

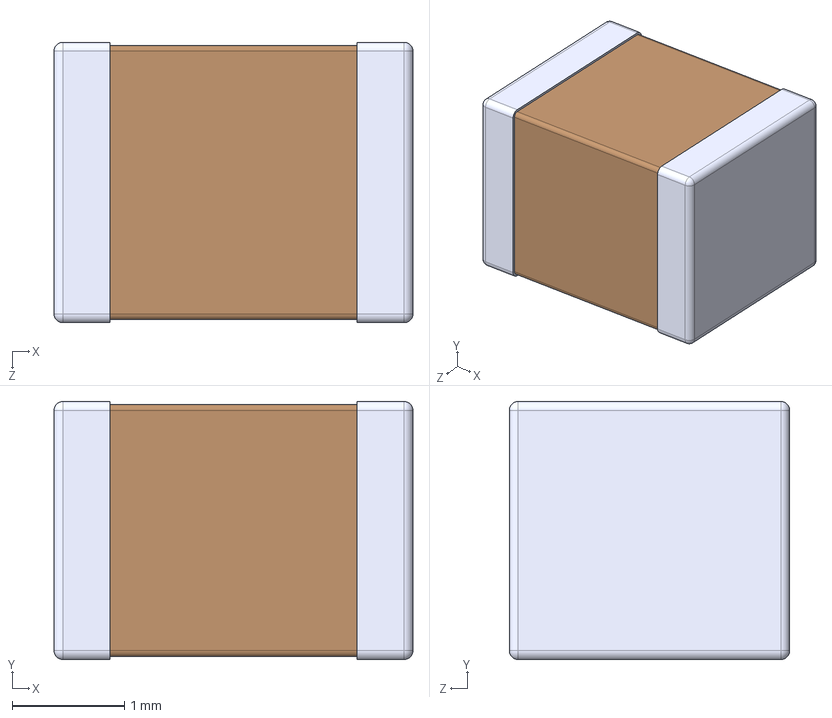
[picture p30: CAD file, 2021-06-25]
PCB/EE464_PCB_Updated/Downloaded_Sym_Foot/InputCeramicCapacitor/C1210C154KCRAC7800.STEP
3.20 x 2.30 x 2.50 mm

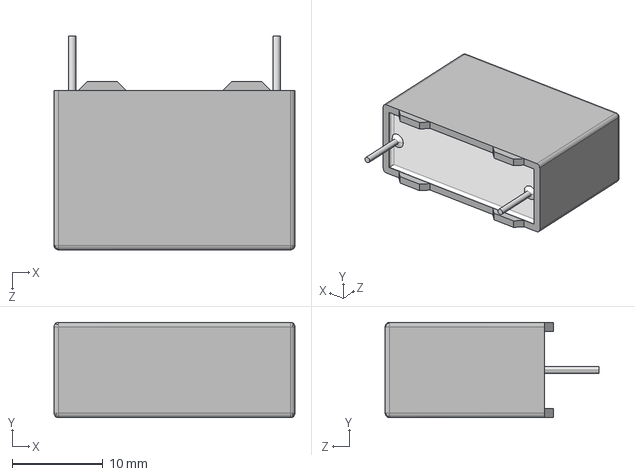
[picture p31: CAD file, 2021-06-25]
PCB/EE464_PCB_Updated/Downloaded_Sym_Foot/InputFilmCapacitor/User Library-FILM_GREY_P2250L2650W1050H1850PD80.step
26.5 x 10.5 x 23.5 mm

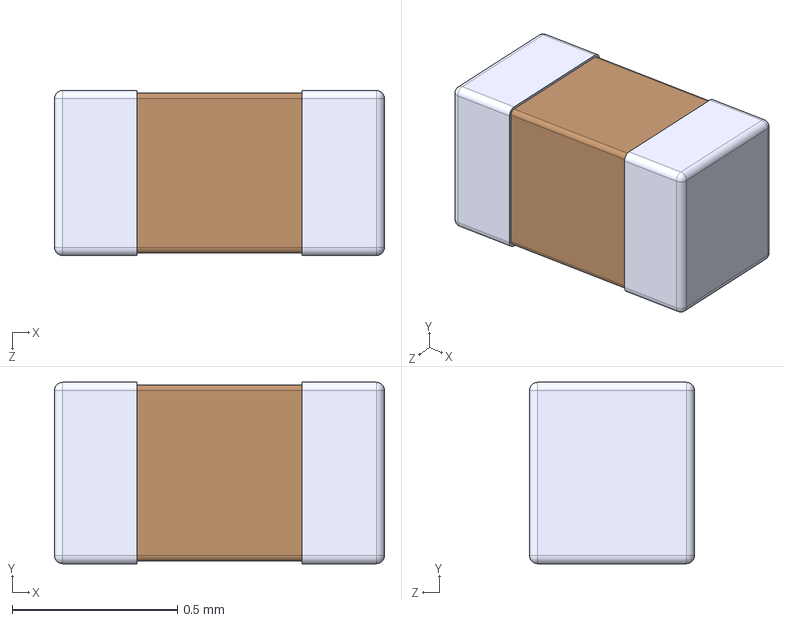
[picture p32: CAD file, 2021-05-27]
PCB/EE464_PCB_Yunus/Downloaded_Sym_Foot/C0402/GRM155R71E104KE14J.STEP
1.00 x 0.55 x 0.5 mm

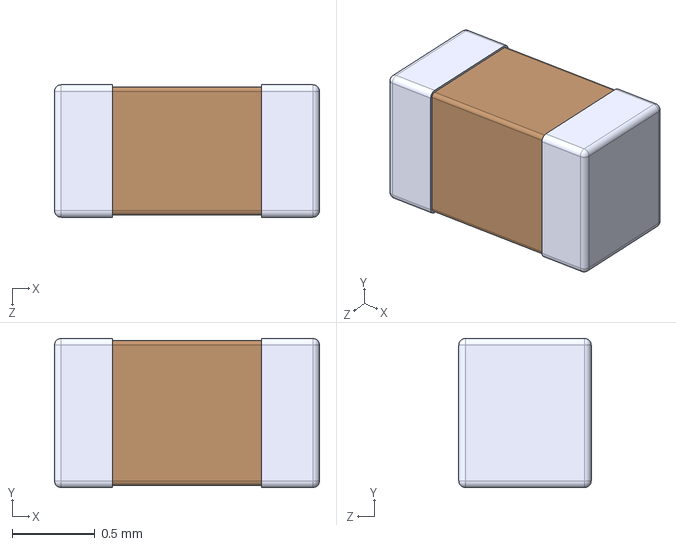
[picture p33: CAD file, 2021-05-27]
PCB/EE464_PCB_Yunus/Downloaded_Sym_Foot/C0603/GRM1885C2A470JA01D.STEP
1.60 x 0.9 x 0.8 mm

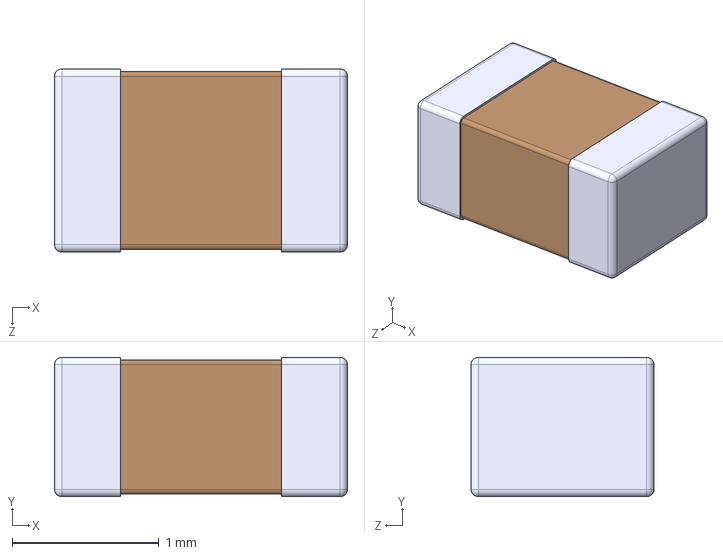
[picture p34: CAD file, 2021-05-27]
PCB/EE464_PCB_Yunus/Downloaded_Sym_Foot/C0805/GRM219R61E475MA73D.STEP
2.00 x 0.95 x 1.25 mm

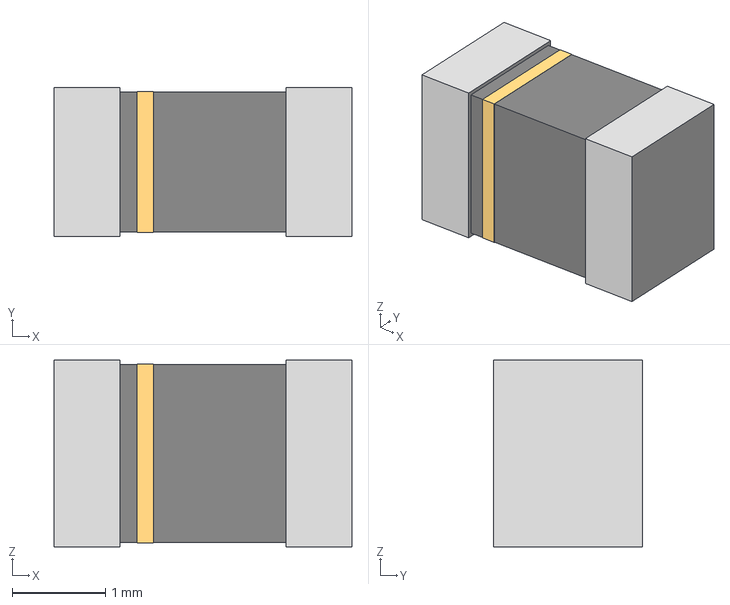
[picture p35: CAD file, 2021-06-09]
PCB/EE464_PCB_Yunus/Downloaded_Sym_Foot/C1206/AltiumDesigner/2021-06-08_23-00-47/G-31_MUR.step
3.20 x 1.60 x 2.01 mm

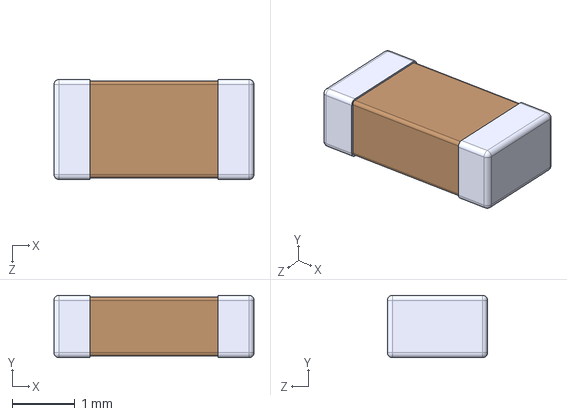
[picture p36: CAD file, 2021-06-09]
PCB/EE464_PCB_Yunus/Downloaded_Sym_Foot/C1206/GRM31A5C2J101JW01D.STEP
3.20 x 1.00 x 1.60 mm

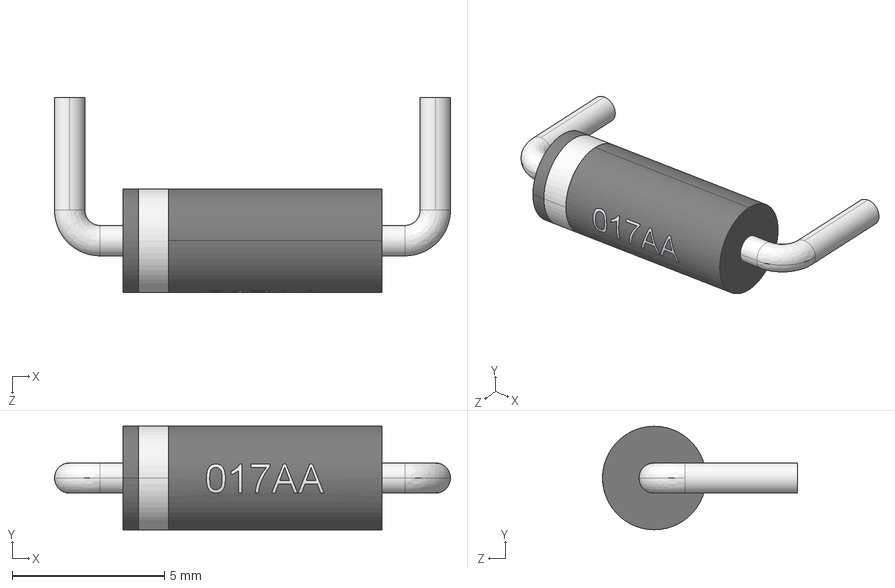
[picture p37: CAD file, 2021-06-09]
PCB/EE464_PCB_Yunus/Downloaded_Sym_Foot/Case 017AA/User Library-Diode Case 017AA.STEP
13.0 x 3.40 x 6.40 mm
refine_Common
refine_Cut001
refine_Sweep001
refine_Sweep
refine_Extrude003
refine_Extrude

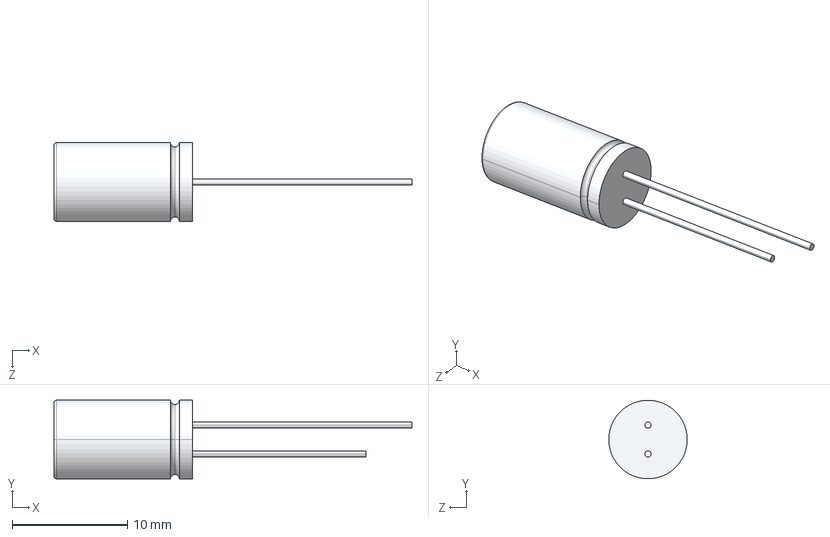
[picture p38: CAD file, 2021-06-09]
PCB/EE464_PCB_Yunus/Downloaded_Sym_Foot/COUT_470uF_6-30x12Dimensions/A759EQ475M2AAAE160.step
31.0 x 6.80 x 6.80 mm

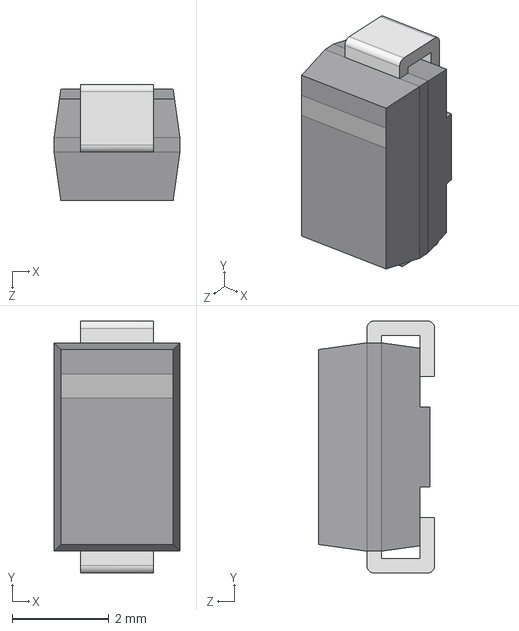
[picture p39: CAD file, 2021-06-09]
PCB/EE464_PCB_Yunus/Downloaded_Sym_Foot/DO214AC-SMA/User Library-DO-214AC SMA.step
2.60 x 5.20 x 2.40 mm

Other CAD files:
PCB/EE464_PCB_Yunus/Downloaded_Sym_Foot/ETD34/User Library-ETD34.STEP
PCB/EE464_PCB_Updated/Flyback/Project Outputs for Free Documents/PCB STEP/[No Variations].x_t
PCB/EE464_PCB_Yunus/Downloaded_Sym_Foot/LT8316IFE_UltraLib/AltiumDesigner/2021-05-20_21-10-27/TSSOP_20_ADI.step
PCB/EE464_PCB_Yunus/Downloaded_Sym_Foot/R0603/User Library-CR1608-0603.step
PCB/EE464_PCB_Yunus/Downloaded_Sym_Foot/R2512/70408497.stp
PCB/EE464_PCB_Yunus/Downloaded_Sym_Foot/Rsense1220/AltiumDesigner/2021-05-21_21-18-42/RES_1220_SUS.step
PCB/EE464_PCB_Yunus/Downloaded_Sym_Foot/SOD128/User Library-SOD128.step
PCB/EE464_PCB_Yunus/Downloaded_Sym_Foot/TO220-AB/stps20h100ct.stp

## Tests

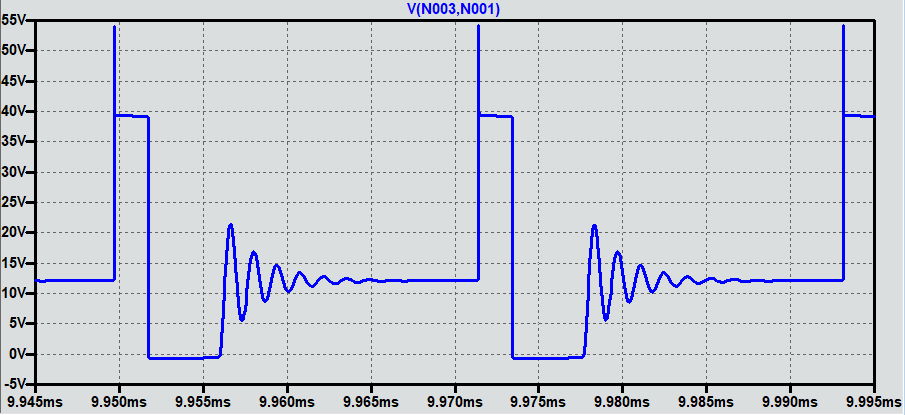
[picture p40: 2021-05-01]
simulation results/220V %10 load/Vdiode.png

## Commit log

2021-04-25 Controller ic selection
    - LT3805 has a good performance. Optocoupler needed.
    - Innoswitch needs to be modeled. How realistic would it be?
    - LT8316 has a poor voltage regulation. Last choice
2021-04-25 Matlab codes and controller modeling added
    The matlab codes for losses, boundary for DCM, determination of output capacitanca, Inductor current ripple have been added.
    Also, some works for PowiGAN controller by Power Integrations modeling have been added
2021-04-26 Peak current detection added
    The peak current in DCM and CCM is detected with added if conditions
2021-04-26 SkinDepth, AWG and resistance calculations added
    Skin depth calculation according to frequency and temperature has been added. Also some resistance calculation are added based on selection of AWG of cable
2021-04-26 RMS calculation is updated
    Before, RMS is calculated for just duty cycle. However, the optimization for cable selection need RMS calcualtion for complete switching period. Therefore, the previous calculations are multiplied wi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
2021-04-28 opto driver datasheet
2021-04-28 Adjusted opto driver compensation for a more stable response
2021-04-30 Flyback GUI constructed
    The GUI for flyback calculations in terms of Lm,fs,Pout,TurnsRatio, Core parameters is useful. The constructed GUI will be enhanced more for winding design, loss calculations, capacitor selection, se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
2021-05-01 Verified Simulation results
    400V full load and 220V %10 load
2021-05-02 MOSFET LTSpice library
    For including it into the LTSpice;
    - open ,lib file in LTSpice
    - Fİnd MOSFET, right click to the SUBCKT, click create symbol
    - Say yes to everything, your model is in the auto generated components
2021-05-02 Some modifications in simulation model
    Dont forget to include new MOSFET model!!!
2021-05-20 heatsink for the output diode
2021-05-24 Some modifications
    -Thermal analysis is verified
    -Diode is changed. All hail the new diode!
    -SPICE model for the diode can be found inrelated folder.
    -Contact mehmet.kl to learn how to add model in LTspice
2021-05-27 PCB files added
    [2021-05-20_21-10-27.PcbLib, 2021-05-20_21-10-27.SchLib, 2021-05-21_21-18-42.PcbLib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]
2021-05-27 Schematic Drawing
    [Flyback.SchDoc, Flyback_Schlib.SchLib]
2021-06-07 magnetics final
2021-06-09 Symbols, Footprints and 3D Completed
    [2021-05-20_21-10-27.PcbLib, 2021-05-20_21-10-27.SchLib, 2021-05-21_21-18-42.PcbLib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]
2021-06-09 Old library file deleted
    [2021-05-20_21-10-27.PcbLib, 2021-05-20_21-10-27.SchLib, 2021-05-21_21-18-42.PcbLib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]
2021-06-09 Symbols and Footprints Matched
    [Flyback.SchDoc, Flyback_Schlib.SchLib]
2021-06-09 Schematic is finished
    [Flyback.SchDoc]
2021-06-09 To Keep My PCB files
    [2021-05-20_21-10-27.PcbLib, 2021-05-20_21-10-27.SchLib, 2021-05-21_21-18-42.PcbLib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]
2021-06-18 PCB Files Updated
    Grounds seperated in schematic.
    Connectors and input caps added.
    [2501-2-00-80-00-00-07-0--3DModel-STEP-56544.STEP, C1210C154KCRAC7800.STEP, Flyback.PcbDoc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]
2021-06-25 TVS is added
    [Flyback.PrjPcb, Flyback.SchDoc, Flyback_PcbLib.PcbLib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]
2021-06-25 Schematic updated
    [Flyback.SchDoc]
2021-06-25 Protection components are added
    [P4SMASeries_LTF.step]
2021-06-27 mosfet model added
2021-06-30 Ready to Draw Layout
    Some Footprints assigned
    Some Rules are checked and set
    [Flyback.PcbDoc, Flyback.PrjPcb, Flyback.SchDoc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]
2021-06-30 Clamp Zener Changed and PCB Started
    [Flyback.PcbDoc, Flyback.SchDoc, Flyback_PcbLib.PcbLib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]
2021-07-01 PCB Drawing ongoing
    Primary side power switch loop drawn
    Input loop and Controller placements done
    [0751.0110_1.STEP, Flyback.PcbDoc, Flyback.PrjPcb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]
2021-07-02 PCB Almost Finished
    Primary Side completed nearly
    [Flyback.PrjPcb, Flyback.SchDoc, Flyback_PCB.PcbDoc]
2021-07-02 PCB Completed except ground cap
    [Flyback_PCB.PcbDoc]
2021-07-02 PCB is finished
    [Flyback.PrjPcb, Flyback_PCB.PcbDoc]
2021-07-02 CAD outputs
2021-07-02 Export Step file of PCB
    [Flyback.PrjPcb, [No Variations].x_t]
2021-07-02 EMN File for CircuitWorks Exported
    [[No Variations].brd]
2021-07-03 Board shape a bit changed and thermal vias added
    [Flyback.PrjPcb, Flyback_PCB.PcbDoc]
